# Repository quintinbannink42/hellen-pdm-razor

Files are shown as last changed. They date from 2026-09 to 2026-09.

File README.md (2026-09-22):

# PowerCore

Hellen-One **hardware** for **PowerCore**, a standalone automotive power distribution module (PDM) with a **Link Razor PDM**-compatible SuperSeal loom.

| | |
|---|---|
| **Product** | **PowerCore** (not an engine ECU) |
| **Connector** | 26-pin AMP SuperSeal 1.0 (Link “Connector C”) — pinout in [CONNECTOR.md](CONNECTOR.md) |
| **Main power** | M6 + / − (VBAT / GND), not on the SuperSeal |
| **MCU module** | [mega-mcu144](https://github.com/andreika-git/hellen-one/tree/master/modules/mega-mcu144) **rev ≥ 0.7** (STM32F767) |
| **I/O target** | 4× high-power (25 A / 80 A peak class) + 8× ADIO (8 A) |
| **KiCad stem** | `pdmrazora` (hellen-one: no dashes/underscores — **do not rename**) |
| **GitHub path** | `hellen-pdm-razor` (legacy repo name; product name is PowerCore) |
| **Default branch** | `main` (required by hellen-one automation) |

> **This is NOT [HELLCORE](https://github.com/quintinbannink42/HELLCORE).** HELLCORE is a separate project. PowerCore is a Hellen-One PDM carrier that matches the Link Razor loom connector.

Former working names (docs/history only): `hellen-pdm-razor`, Hellen Razor-class PDM.

## Docs

| File | Contents |
|---|---|
| [POWERCORE_BRIEF.md](POWERCORE_BRIEF.md) | Product identity, tokens, Razor loom compatibility |
| [CONNECTOR.md](CONNECTOR.md) | Exact Razor-compatible 26-pin + M6 pinout (authoritative) |
| [PINMAP.md](PINMAP.md) | mega-mcu144 edge → HP / ADIO / system nets |
| [REV1_SPEC.md](REV1_SPEC.md) | Goals, architecture, e-fuse behaviour |
| [BLOCK_DIAGRAM.md](BLOCK_DIAGRAM.md) | Carrier block diagram |
| [BOARD.md](BOARD.md) | What’s stubbed vs next; module placement steps |
| [HARDWARE_BOM.md](HARDWARE_BOM.md) | Chosen PNs, kILIS, AmpsPerVolt TODOs |

## KiCad project

Open with **KiCad 8.x** (Hellen mega-mcu144 0.7 is K8). KiCad 9 also works. KiCad 6/7 will not open this module.

- `pdmrazora.kicad_pro` / `.kicad_sch` / `.kicad_pcb` (no dashes/underscores — hellen-one requirement)
- `revision.txt` → `BOARD_PREFIX=pdm` `BOARD_SUFFIX=razor` `BOARD_REVISION=a`

Schematic: SuperSeal **TE 6473418-1** vertical (Link Razor-compatible nets; same pin numbers as former RA 9-6437287-8), **split** M6 bolt-through bobbins (J2 VBAT+ north / J3 GND south, drivers between) + power entry/IGN_SW divider, sheets **MM144** / **HP** (**BTS50010-1TAD** ×4) / **ADIO** (**BTS7004-1EPP** ×8 + sense/PU). PCB: **109×98 mm** frame (was 104×93), mega-mcu144 0.7 west of a vertical SuperSeal EMI wall, power/PROFET east. J2 VBAT+ and J3 GND stay on opposite edges of the power field; HP×4 and ADIO×8 are mirrored about x=80. `PWR_OUT1–4` run on exposed F.Cu (F.Mask opened over the copper) with short B.Cu hops only at the module pad wall. DRC shorts/crossings/clearance are 0; the board is not fab-clean (see [BOARD.md](BOARD.md)). Parts/kILIS: [HARDWARE_BOM.md](HARDWARE_BOM.md).

## How to build (Hellen-One)

1. `git clone --recurse-submodules https://github.com/quintinbannink42/hellen-pdm-razor.git`
2. Open with **KiCad 8.x** (Hellen mega-mcu144 0.7 is K8). KiCad 9 also works. KiCad 6/7 will not open this module.
   Open `pdmrazora.kicad_pro`.
3. mega-mcu144 **0.7** is already on the frame (`M1000`). Refresh from `hellen-one/modules/mega-mcu144/0.7/` if the submodule moves.
4. Route SuperSeal / M6 / module pads per CONNECTOR.md / PINMAP.md; replace HP/ADIO schematic stubs with chosen PNs + sense parts.
5. Push to **`main`**. GitHub Action `.github/workflows/create-board.yaml` calls hellen-one create-board to merge module gerbers into `boards/`.
6. Daily workflows keep `hellen-one` and `kicad6-libraries` submodule refs updated.

Frame rules (from hellen-example FAQ):

- No `-` or `_` in KiCad filenames
- `aux_axis_origin` required; board origin at **bottom-left** (no negative coordinates)

## Firmware intent

Firmware is **not** this repo. See **[fw-powercore](https://github.com/quintinbannink42/fw-powercore)** (rusEFI custom board overlay: electronic fuse + channel map), based on [fw-custom-hellen144-f4](https://github.com/rusefi/fw-custom-hellen144-f4) / `hellen-common-mega144.mk`, with `protected_gpio` for HP1–4 + ADIO1–4 first. See PINMAP.md and REV1_SPEC.md.

## Submodules

```
hellen-one          https://github.com/andreika-git/hellen-one
kicad6-libraries    https://github.com/rusefi/kicad6-libraries
```

Skeleton mirrors [rusefi/hellen-example](https://github.com/rusefi/hellen-example).

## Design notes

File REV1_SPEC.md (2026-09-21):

# PowerCore — Rev 1

**Status:** Rev 1 design baseline  
**Product:** PowerCore (standalone PDM; Link Razor-compatible SuperSeal loom)  
**MCU module:** Hellen mega-mcu144 (STM32F767)  
**Firmware base:** [fw-powercore](https://github.com/quintinbannink42/fw-powercore) (rusEFI custom board)  
**I/O target:** Link ECU Razor PDM I/O + protection parity  

Former working names (docs/history only): `hellen-pdm-razor`, Hellen Razor-class PDM. KiCad stem stays **`pdmrazora`**.

## Goals (rev 1)

Ship a first PowerCore Hellen-One carrier + firmware that can:

1. Drive **4× high-power** channels at **25 A continuous / 80 A peak**, HS (DIR/H-bridge optional if pins allow).
2. Provide **8× ADIO** at **8 A** high-side, with analog/digital input modes and software pull-ups.
3. Log **per-channel current** on high-power outputs (and ADIO when used as outputs).
4. Implement programmable electronic-fuse behaviour (inrush window, overcurrent, trip time, retry/latch, over-temp).
5. Speak **USB** + **CAN**; expose channels in TunerStudio / gauges.

Non-goals for rev 1: sealed Link-style CNC housing, PC “PDM Link” clone UI, full galvanic isolation, second MCU.

## Architecture

```
                    +------------------+
   VBAT ------------| Power entry      |
                    | TVS, reverse,     |
                    | fuse, sense      |
                    +--------+---------+
                             |
              +--------------+--------------+
              |                             |
     +--------v--------+           +--------v--------+
     | HP stage x4     |           | ADIO stage x8   |
     | PROFET / half-  |           | 8 A high-side   |
     | bridge capable  |           | + pin mux       |
     | IS -> ADC       |           | V/I -> ADC      |
     +--------+--------+           +--------+--------+
              | EN/PWM/DIR                  | EN/PWM/PU
              |                             |
              +--------------+--------------+
                             |
                    +--------v---------+
                    | mega-mcu144      |
                    | STM32F767        |
                    | USB / CAN / ADC  |
                    +--------+---------+
                             |
                    +--------v---------+
                    | SuperSeal I/O    |
                    | + USB-C          |
                    +------------------+
```

## Electrical targets (from Link Razor)

| Block | Count | Continuous | Peak / trip notes | Modes |
|---|---:|---|---|---|
| High-power | 4 | 25 A | 80 A safe peak; measure to ~60 A | HS (rev1); LS / half / full bridge stretch |
| ADIO | 8 | 8 A HS out | Fixed ~10 A hardware trip class | Analog in, digital in, HS out; ADIO1–4 PWM out; ADIO5–8 freq/PWM in |
| Supply | — | 6–24 V | 12/16 V nominal | Quiescent &lt;300 mA outputs off |
| Aux | — | 5 V sensor @ 50 mA/pin class | — | Sensor GND separate from chassis |

## Firmware electronic fuse (clone Razor behaviour)

Per high-power channel:

- **Inrush** limit + trip time + duration window after turn-on
- **Overcurrent** limit + trip time after inrush window
- **Fast short** path (~60 A class) → immediate off
- **Retry** (count + delay) or **latch-off**
- **Over-temp** board threshold with hysteresis
- Optional soft-start duty ramp on PWM channels

ADIO outputs: simpler fuse (fixed hardware trip + software trip time / retry / latch).

## Pin budget (mega-mcu144)

Provisional function map — STM32 / MM144 edge names filled from module docs in `PINMAP.md`.

| Function | Count | Notes |
|---|---:|---|
| HP_EN / PWM | 4 | TIM PWM ≥10 kHz |
| HP_DIR | 0–4 | Stretch; omit on first spin if copper tight |
| HP_ISENSE ADC | 4 | Continuous current |
| ADIO_EN / PWM | 8 | 4 with PWM timers |
| ADIO_PU | 8 | Soft 4k7 to 5 V |
| ADIO_SENSE ADC | 8–16 | Prefer V+I; 144 should allow at least V **or** I per pin without mux |
| Freq / PWM in | 4 | ADIO5–8 input path |
| VBATT / 5V / TEMP ADC | 3 | |
| USB | 1 | On module |
| CAN | 1 | On module |
| Status LEDs | ≥4 | Module LEDs + carrier if needed |
| PWR_EN | 1 | Switched 5 V sensor rail |

## Rev 1 hardware BOM direction

- **MCU:** Hellen mega-mcu144 module footprint
- **HP switches:** Infineon PROFET+2 / PROFET (e.g. BTS70xx class sized for 25 A continuous + inrush); IS pin to ADC via Rl
- **ADIO switches:** smaller PROFET / high-side (8 A continuous)
- **Connector:** 26-pin SuperSeal family (Razor-like dual pins on HP feeds)
- **USB-C** for config (RusEFI USB)
- **CAN** transceiver on module or carrier as per MM144 edge

## Firmware repo layout (planned)

```
fw-powercore/
  meta-info.env
  board.mk
  board_configuration.cpp   # pin map + defaults
  prepend.txt
  firmware/                 # electronic fuse + channel state machine
  README.md
```

Build via RusEFI custom-board GitHub Action pattern (`rusefi/fw-custom-example`).

## Build order

1. Freeze pin map (`PINMAP.md`) against MM144 edge  
2. Hellen-One KiCad frame + HP/ADIO modules  
3. Bring-up firmware: toggle HP/ADIO, read ADCs in TunerStudio  
4. Electronic-fuse state machine  
5. CAN channel command / status frames  

## Open items for next docs

- Exact MM144 edge → STM32 assignment (`PINMAP.md`)
- Chosen PROFET PNs and sense-resistor cal
- Connector pinout drawing
- CAN DBC draft

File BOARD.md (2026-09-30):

# Board status — PowerCore (`pdmrazora` rev a)

Open with **KiCad 8.x** (Hellen mega-mcu144 0.7 is K8). KiCad 9 also works. KiCad 6/7 will not open this module. File format stays **20240108 / generator_version 8.0**. Stem is `pdmrazora`.

## This commit — leftover rats and ADIO5/ADIO8 fill

Closes rats left after the U14/U16/U18 reconnect, and brings the two 2 oz fill residuals back to the 8 A floor. Applicators: `scripts/close_remaining_rats.py` (ADIO5/ADIO8 polish and the five EN ties) and `scripts/route_short_rats.py` (short pairs). Both are already applied; re-running them duplicates copper. `scripts/cut_crossings_sexp.py` was not replayed. `scripts/even_2oz_pour.py` was not re-run. No footprint moved. ADIO2 was not edited. HP pours were not trimmed. F1 stays open. There is still no SENSOR_GND pour. The Razor loom / SuperSeal map is unchanged. No gerbers. Pins were not frozen.

ADIO5 polish is a B.Cu sliver `A5_slot_ext` under the F slot only, outline (111.00, 45.46)–(113.45, 45.78), overlapping the ribbon bottom at y=45.58. The top of that slot stays against ADIO4. The ribbon was not lowered west of the slot, where ADIO6 sits 0.23 mm under it. ADIO8 polish moves the west edge of `A8_drop_F` from x=47.12 to x=47.08, into the gap beside PWR_OUT4 (fill ends at x=46.68). The east edge stays on ADIO6. Neither edit takes copper from ADIO2 or from a PWR_OUT pour.

Filled necks, 0.01 mm raster of the zone fill, same cuts on main and on this board except the two pinches:

| Path | Filled series neck | 2 oz floor |
|---|---|---|
| ADIO1 | 1.76 + 1.76 mm = 3.52 mm F+B, unchanged | 1.74 mm |
| ADIO2 | corridor not edited (4.53 mm) | 4.53 mm |
| ADIO3 | 1.03 + 1.03 mm = 2.06 mm F+B, unchanged | 1.74 mm |
| ADIO4 | alley 1.74 mm, drop 1.74 mm, throat 0.94 + 1.00 mm | 1.74 mm |
| ADIO5 | slot B **1.71 → 1.83 mm** (x=111.05–113.35) | 1.74 mm |
| ADIO6 | alley 1.74 mm, throat 0.88 + 0.88 mm = 1.76 mm | 1.74 mm |
| ADIO7 | east B ribbon 3.80 mm, unchanged | 1.74 mm |
| ADIO8 | drop **1.73 → 1.77 mm**; alley 1.73 mm unchanged (main is also 1.73); throat 0.90 + 0.90 mm | 1.74 mm |
| PWR_OUT1 | 19.21 mm F | 8.36 mm |
| PWR_OUT2 | 16.72 mm F | 8.36 mm |
| PWR_OUT3 | 21.40 mm F | 8.36 mm |
| PWR_OUT4 | 8.70 + 8.70 mm = 17.40 mm F+B | 8.36 mm |

The ADIO8 alley was already 1.73 mm filled on main. #26 wrote 1.74 mm for that alley. This pass did not narrow it and did not jog it: the named residual was the drop. Widening the alley would crowd the next even pour.

| Issue | Before (main `fc83f20`) | After |
|---|---:|---:|
| shorting_items / crossings / clearance / courtyard / padstack | 0 | **0** |
| unconnected_items | 158 | **141** |
| SuperSeal nets edited | — | **no** |

`kicad-cli` 8.0.9, `pcb drc --severity-error`. Violations 0. Unconnected 141.

What closed: EN pad 2–3 on U11 (`OUT_PWM5`), U13 (`OUT_PWM7`), U15 (`OUT_IO5`), U17 (`OUT_IO7`), and U12 (`OUT_PWM6`), 0.20 mm on F.Cu. Short same-net stitches on GND, SENSOR_5V (including SuperSeal pins 11 and 5, already the same net), SENSOR_GND (pins 12 and 6, already the same net), IN_AUX1 (C10.1–R10.2), and IN_VIGN (R2.1–R1.2). Ten M1000 GND fingers get a 0.20 mm exit out of the pour keepout (tracks are allowed there). Pre-fuse VBAT ties C1 to C2 and D1 toward the north zone with 0.40 mm tracks that stay north of the fuse body. The B.Cu GND zone self-rat at (−31.2, −39.2) closed on the refill.

Still open, and why:

- **U12 GND.** Pad 1 at (81.95, 144.05) to the U18 via at (103.55, 147.95). ADIO2 seals the west and south of that pad. The east gutter to the VBAT column is about 0.40 mm, and a via does not fit between B.Cu ADIO2 (ends x=82.70) and F.Cu VBAT (starts x=83.0). Moving U12 would pull the OUT pads off the 4.53 mm corridor. Footprint stays.
- **F1.** Zone (68.5, 1) to zone (54.5, 27.5) stays open. The schematic uses one VBAT net through the fuse.
- **VBAT post-fuse islands.** Three self-rats on the F zone at (54.5, 27.5). The split is the #26 ADIO4/ADIO8 sense slot near x=86.7–87.9. Bridging it cuts those taps. There is no B.Cu VBAT under the slot. M1000 N27 at (−11.5, 26.2) is still open to the post-fuse zone.
- **VBAT north stub.** Track at (102.65, −26.25) to the D1 track at (112, 10.15). C1, C2, and D1 are tied on the pre-fuse side; that stub still does not meet D1.
- **IN_AUX4**, four rats. The U4 stub (101.65, 40.47) to (97.6, 32) is blocked by the U4 VBAT pad and PWR_OUT4. M1000 S10 (2.70, 65.70) is still open to C40.1 and R40.2.
- **Sense pad 2.** R201 (ADIO1), R202 (ADIO2), R203 (ADIO3), R205 (ADIO5), R207 (ADIO7). Schematic intent is pad 2 on ADIOn and pad 1 on SENSOR_5V, same as the even taps #26 already closed. These five sit in the VBAT / SENSOR_5V row at y=56.20. A 0.12 mm path to the pour is blocked (nearest fill is 4.6 mm to 20 mm away). Left open.
- **F.Cu GND slivers** at (68, 76.2), and U15 / U17 pad 1. The slivers sit against ADIO2. A via there hits the ADIO2 ribbon. Not cut. One M1000 GND finger at (14.2, 59.35) has no clear exit. The other fingers are 0.20 mm SMD with a separate F and B pad, so a one-layer exit leaves the other finger ratted. They are too narrow for a via.
- **Longer signal rats** (IN_RES, IN_MAP, IN_O2S, and the rest of the 141). The short router stops at 8 mm. The paths run through foreign pours. Those pours were not sliced.

## Previous commit — reconnect U14/U16/U18 and even sense

Moved drivers U14, U16, and U18 are tied again: VBAT pad 15, GND pad 1, EN pads 2–3, and the IS pad. Sense pads R204.2, R206.2, and R208.2 land on ADIO4/6/8 with a 0.12 mm tap, the same class of connection as the odd-channel sense pads (those odd pads stay open). Applicator: `scripts/reconnect_moved.py`. `scripts/cut_crossings_sexp.py` was not replayed. `scripts/even_2oz_pour.py` was not re-run.

VBAT branches are priority 2 on B.Cu, the same 3.6 mm class as the existing driver column, not a new 25 A neck. Signals use exclusive south-east lanes (0.20 mm, 0.15 mm in the east margin) and 0.50 mm vias. The only preserved-pour edit is the east tip of `A1/A3/A5/A7_spur_Fw`, pulled from x=104.25 to x=102.20 so a sense slot fits beside PWR_OUT2. Spur height stays 3.80 mm. ADIO2 was not edited. HP pours were not trimmed. F1 stays open. There is still no SENSOR_GND pour. The Razor loom / SuperSeal map is unchanged. No gerbers. Pins were not frozen.

Filled necks on the same cuts, before and after this refill, did not move:

| Path | Filled series neck | 2 oz floor |
|---|---|---|
| ADIO1 | 1.76 + 1.76 mm = 3.52 mm F+B (documented 3.56) | 1.74 mm |
| ADIO2 | corridor not edited (4.53 mm) | 4.53 mm |
| ADIO3 | 1.03 + 1.03 mm = 2.06 mm F+B (documented 2.08) | 1.74 mm |
| ADIO4 | alley 1.75 mm, drop 1.74 mm, throat 0.94 + 1.00 mm | 1.74 mm |
| ADIO5 | 1.71 mm B through the F slot (same as the 2 oz fill) | 1.74 mm |
| ADIO6 | alley 1.74 mm, throat 0.88 + 0.88 mm = 1.76 mm | 1.74 mm |
| ADIO7 | east B ribbon 3.80 mm (documented 3.82) | 1.74 mm |
| ADIO8 | alley 1.74 mm, drop 1.73 mm, throat 0.90 + 0.90 mm | 1.74 mm |
| PWR_OUT1 | 16.72 mm, outline not edited | 8.36 mm |
| PWR_OUT2–4 | outlines not edited; class pours stay 16.72 mm | 8.36 mm |

ADIO5's filled reading is 1.71 mm on both the 2 oz board and this refill. The outline at that slot is still the 1.77 mm ribbon from the 2 oz merge. Nothing in this pass cut it.

| Issue | Before | After |
|---|---:|---:|
| shorting_items / crossings / clearance / courtyard / padstack | 0 | **0** |
| unconnected_items | 174 | **158** |
| SuperSeal nets edited | — | **no** |

The drop is the moved-driver pads and the three even sense pads. U12's GND rat to the new U18 via is still open. Old VBAT zone rats are still there, and the refill added one VBAT zone rat, one GND zone rat, and one IN_AUX4 rat. `kicad-cli` 8.0.9, `--severity-error`. Violations 0. Unconnected 158.

## Previous commit — board-wide 2 oz, ADIO4/6/8 at 8 A

Copper weight is **2 oz (70 µm) on both layers, for the whole board**. Fab notes are in the title block and on Dwgs.User. Stackup in `pdmrazora.kicad_pcb`: F.Cu 0.07 mm, FR4 core 1.46 mm, B.Cu 0.07 mm, finished 1.6 mm. Numbers: [scripts/adio_2oz.txt](scripts/adio_2oz.txt). Applicator: `scripts/even_2oz_pour.py` (run only from a clean board).

Board-wide 2 oz is the normal fab path. A board house sets copper weight per layer for the whole panel, not for a region of ADIO4/6/8. Selective heavy copper is a different process. The HP pours were already wider than the new 25 A line, so the whole board going to 2 oz does not require trimming them.

IPC-2221A external, k = 0.048, ΔT = 20 °C. Width scales as 1/thickness. The 1 oz ruler was 8 A → 3.47 mm and 25 A → 16.72 mm. At 2 oz that is **8 A → 1.74 mm** (1.736 mm) and **25 A → 8.36 mm** (8.359 mm). Netclass defaults in `pdmrazora.kicad_pro` follow that (ADIO_OUT 1.74, HP_OUT and VBAT 8.36). Existing HP and VBAT copper was not narrowed to the new default.

2 oz does not open the stock SuperSeal cage. With 2.0 mm pads the even door is still F+B 1.20 mm, under 1.74 mm. Pins 16, 17, 18 and 22, 23, 24, 25 are 1.60 mm pads (0.15 mm annular ring on the 1.3 mm drill). Pins 15 and 21 and the HP pads stay 2.0 mm. Pin 25 stays N/C. The Razor loom map is unchanged.

U14, U16, and U18 still had to move. At 1.74 mm, U14's old OUT sat inside the ADIO2 corridor, and U16/U18 still had no path into the y≈60 bay without cutting the odd pours, the HP pours, or ADIO2. They sit in the empty south-east: U18 (108, 150), U16 (120, 146), U14 (120, 156), all rotation 0. U12 stays at (84.80, 146).

The odd east ribbons were narrowed where a 1.74 mm even throat cannot exist beside a 3.80 mm odd ribbon on a 3.0 mm pitch. Downstream odd spurs and columns were not cut. ADIO2 was not edited.

| Path | Series neck (filled) | 2 oz / 20 °C target |
|---|---|---|
| ADIO1 | 1.78 + 1.78 mm = 3.56 mm F+B (pour not edited; prior notch reading 3.51 mm) | 1.74 mm |
| ADIO2 | 4.53 mm F+B corridor, not edited | 1.74 mm |
| ADIO3 | 1.04 + 1.04 mm = 2.08 mm F+B (was 3.80 mm B) | 1.74 mm |
| ADIO4 | 1.76 mm (throat F+B 1.98 mm, gate under A7 is F+B 3.18 mm) | 1.74 mm |
| ADIO5 | 1.74 mm B through the F slot at x=111.2–114.0 (was 3.80 mm B) | 1.74 mm |
| ADIO6 | 1.76 mm (throat F+B 1.80 mm) | 1.74 mm |
| ADIO7 | 3.20 mm F+B at the pin (1.60 + 1.60); east B ribbon still 3.82 mm | 1.74 mm |
| ADIO8 | 1.76 mm (throat F+B 1.84 mm) | 1.74 mm |
| PWR_OUT1–4 | unchanged 16.72 mm class (west leg (8.70−0.30)×2 = 16.80 mm) | 8.36 mm |

Series neck is the minimum F+B cross-section of one continuous path. F and B add on the same XY. Via drills are stitches, not summed as parallel slots. SuperSeal pads and the PROFET OUT clusters are the pad interface, not the neck.

Outline stays **(−32, −40)–(142, 162)**. F1 stays open (new copper starts at y=34.24; F1 pads are at y=15 and y=24.2). There is still no SENSOR_GND pour. No gerbers. `scripts/cut_crossings_sexp.py` was not replayed. Pins were not frozen. 80 A peak and the 150 A fuse class are still not traces.

| Issue | Before | After |
|---|---:|---:|
| shorting_items / crossings / clearance / courtyard / padstack / mask bridge | 0 | **0** |
| unconnected_items | 183 | **174** |
| Copper weight | 1 oz (not recorded) | **2 oz both layers** |
| SuperSeal nets edited | — | **no** |

Unconnected is lower because the new pours tie the even power paths. It is not zero. The moved drivers' VBAT pad 15, GND pad 1, and signal pads are open, and the sense pads R204.2 / R206.2 / R208.2 are open in the same way as the odd channels. The old VBAT zone rats are still there. `kicad-cli` 8.0.9, `--severity-error`. Violations 0. Unconnected 174.

## Previous commit — ADIO4/6/8 loom reassignment held

Pin reassignment was allowed, including a break from the Link Razor harness map, so ADIO4, ADIO6, and ADIO8 could reach a continuous ≥3.47 mm series neck at 1 oz. No assignment does. The board copper is unchanged. The SuperSeal net list is unchanged. Stackup stays 1 oz. The 8 A line was not derated. Audit: `scripts/even_reassign_audit.py`. Numbers: [scripts/even_reassign_audit.txt](scripts/even_reassign_audit.txt) and [scripts/adio_ampacity.txt](scripts/adio_ampacity.txt).

The upper bound ties every SuperSeal pin that is not already a preserved high-current net onto the candidate at once: pins **3, 4, 5, 6, 10, 11, 12, 16, 17, 18, 25**. Pins 2, 9, and 15 stay ADIO2. Pins 21–24 stay ADIO1/3/5/7. The PWR_OUT pins stay. Signal tracks and GND tracks are ignored (a pour may push them). Pads stay. Preserved zones stay: PWR_OUT1–4, ADIO1/2/3/5/7, VBAT priority ≥2, and VBAT that reaches the fuse band. Priority-1 GND pours are not obstacles. Grid 0.30 mm, clearance 0.20 mm. F and B add on the same XY.

| Path | Series neck under that upper bound | 20 °C need |
|---|---|---|
| ADIO1 | unchanged 3.51 mm | 3.47 mm |
| ADIO3 | unchanged 3.80 mm B | 3.47 mm |
| ADIO5 | unchanged 3.80 mm B | 3.47 mm |
| ADIO7 | unchanged 3.80 mm B | 3.47 mm |
| ADIO2 | unchanged poured 4.53 mm (audit grid reads 4.29 mm to U12) | 3.47 mm |
| ADIO4 | **2.60 mm** to the open field beside U14, then ADIO2 copper at the OUT pads | 3.47 mm |
| ADIO6 | **no positive-width path** to U16 | 3.47 mm |
| ADIO8 | **no positive-width path** to U18 | 3.47 mm |
| PWR_OUT1–4 | unchanged 16.72 mm class | 16.72 mm |

ADIO4's 2.60 mm pinch is (104.6, 114.7): F width is 0 on the edge of PWR_OUT2 `PO2_east`, and B is 2.60 mm in the gap just south of the ADIO7 B spur (y=109.55–113.35). Both are preserved, so that neck was not trimmed. Blanking the ADIO2 tube beside U14 (x=87.2–93.5, y=150.5–161) drops the ADIO2 reading from 4.29 mm to 0.40 mm, pinch (86.9, 144.7), so that tube is the series path to U12, not spare copper around U14.

ADIO6 and ADIO8 sit in the bay at y≈60 (U16 OUT x=72.85, U18 OUT x=95.75). The east alley past x=134 is reached from pin 25 at about 14 mm F+B and still does not enter that bay. The walls are the odd-channel pours (ADIO5 ribbon y=45.15–47.35 across to x=129.8, ADIO7 B ribbon y=40.25–44.05 to x=134, the four spur rows near y=82.5 / 91.5 / 100.5 / 109.5, and the columns at x=122–134) plus PWR_OUT1 `PO1_drop`, PWR_OUT2 `PO2_east` / `PO2_band` / `PO2_col`, and the ADIO2 B ribbon. The earlier ~0.80 mm figure does not survive on this board: `scripts/even_nc_pour.py`'s own corridor, with those pours as obstacles, does not reach U16 or U18. R208 at (94.83, 56.20) is still the crowd beside U18, on the far side of that wall.

Loom delta versus Link Razor: **none**. No pin changed old net to new net.

| Pin | Razor net on main | After this pass |
|----:|---|---|
| 2, 9 | N/C on the loom, ADIO2 on the PCB | same |
| 16 | ADIO4 | same |
| 17 | ADIO6 | same |
| 18 | ADIO8 | same |
| 25 | N/C | same |
| 3, 4, 5, 6, 10, 11, 12 | CANH, IGN_SW, SENSOR_5V, SENSOR_GND, CANL, SENSOR_5V, SENSOR_GND | same |

Outline stays **(−32, −40)–(142, 162)**. F1 stays open. There is still no SENSOR_GND pour. No gerbers. `scripts/cut_crossings_sexp.py` was not replayed. Pins were not frozen.

| Issue | Before | After |
|---|---:|---:|
| shorting_items / crossings / clearance / courtyard / padstack / mask bridge | 0 | **0** |
| unconnected_items | 183 | **183** |
| Board copper edited | — | **no** |
| SuperSeal nets edited | — | **no** |

`kicad-cli` 8.0.9, `--severity-error`. Violations 0. Unconnected 183.

## Previous commit — even ADIO NC bridges

ADIO2 now has a poured series neck of **4.53 mm** F+B, above the 1 oz / 20 °C line for 8 A (3.47 mm). SuperSeal pins 2 and 9 join the ADIO2 net on the PCB so the west cage slots merge into that one corridor. The loom table still calls those pins N/C: no harness wire is added, and no signal pin was reassigned. Applicator: `scripts/even_nc_pour.py`. Numbers: [scripts/adio_ampacity.txt](scripts/adio_ampacity.txt).

Pin 25 stays N/C. Joining it to ADIO8 does not produce a continuous path to U18 at 3.47 mm (widest zone-aware path is about 0.80 mm, pinch beside U18). ADIO4 and ADIO6 stay at that same ~0.80 mm path once the odd pours and the PWR_OUT copper are treated as obstacles. The pad-only sum of every 0.52–0.60 mm slot around one pin (~5.66 mm) is not a series neck and was not poured. ADIO7's B.Cu leg was not moved.

Outline stays **(−32, −40)–(142, 162)**. F1 stays open. There is still no SENSOR_GND pour. Copper is still 1 oz. No gerbers.

| Path | Series neck | 20 °C need |
|---|---|---|
| ADIO1 | 1.75 + 1.76 mm = 3.51 mm, no via | 3.47 mm |
| ADIO3 | 3.80 mm B.Cu under PWR_OUT2 east | 3.47 mm |
| ADIO5 | 3.80 mm B.Cu under PWR_OUT2 east | 3.47 mm |
| ADIO7 | 3.80 mm B.Cu (outline not moved) | 3.47 mm |
| ADIO2 | 4.53 mm F+B filled corridor via pins 2 and 9 | 3.47 mm |
| ADIO4 | not poured; widest path ~0.80 mm | 3.47 mm |
| ADIO6 | not poured; widest path ~0.80 mm | 3.47 mm |
| ADIO8 | not poured; widest path ~0.80 mm with pin 25 | 3.47 mm |
| PWR_OUT1–4 | unchanged 16.72 mm class pours | 16.72 mm |

Series neck is the minimum F+B cross-section of one continuous path (filled copper, layers on the same XY add, via drills are holes the path goes around). It is not the sum of parallel slots.

| Issue | Before | After |
|---|---:|---:|
| shorting_items / crossings / clearance / courtyard / padstack / mask bridge | 0 | **0** |
| unconnected_items | 184 | **183** |
| SENSOR_GND pours | 0 | **0** |
| F1 bridged | no | **no** |
| In1.Cu count | 181 | **181** |

Unconnected is one lower. ADIO2's power path dropped from 7 open items to the one sense pad (R202.2 at y=56.20), same class as the odd channels. GND went 55 → 60 because the B.Cu ribbon pushes priority-1 GND aside. `kicad-cli` 8.0.9, `--severity-error`. `scripts/cut_crossings_sexp.py` was not replayed. Pins were not frozen.

## Previous commit — even ADIO fanout

ADIO2, ADIO4, ADIO6, and ADIO8 still do not have a 3.47 mm neck. A read-only corridor search (`scripts/even_adio_fanout.py`, also `scripts/adio_ampacity.py --even-audit`) may leave each even pin in any direction, on F.Cu and on B.Cu. The widest single neck is **0.60 mm on a layer, F+B 1.20 mm**. The 1 oz ceiling, with copper flush to the 1.3 mm drills and zero clearance (a short to the next plating), is **F+B 3.40 mm**, still under 3.47 mm. Detail: [scripts/adio_ampacity.txt](scripts/adio_ampacity.txt).

Odd ADIO necks and the PWR_OUT pours were not rewritten. The board file was not edited. Outline stays **(−32, −40)–(142, 162)**. F1 stays open. There is still no SENSOR_GND pour.

| Path | Series neck | 20 °C need |
|---|---|---|
| ADIO1 | 1.754 + 1.760 mm = 3.51 mm, no via | 3.47 mm |
| ADIO3 | 3.80 mm B.Cu under PWR_OUT2 east | 3.47 mm |
| ADIO5 | 3.80 mm B.Cu under PWR_OUT2 east | 3.47 mm |
| ADIO7 | 3.80 mm B.Cu (F ends at the PWR_OUT3 column) | 3.47 mm |
| ADIO2, 4, 6, 8 | 0.60 + 0.60 mm = 1.20 mm after the fanout search | 3.47 mm |
| PWR_OUT1–4 | unchanged 16.72 mm class pours | 16.72 mm |

Vias do not help: the SuperSeal pads are PTH on both layers. Moving the even drivers, opening a south or east corridor, or growing the board does not widen the door, which is upstream of that copper. Giving NC pins 2 and 9 to one even net, and pin 25 to another, can open ADIO2 or ADIO4 (not both) and ADIO8. ADIO6 stays at 1.20 mm even if it takes every NC pin. That reassignment was not applied; the Razor pin map is unchanged. Parallel 0.60 mm slots were not poured.

| Issue | Before | After |
|---|---:|---:|
| shorting_items / crossings / clearance / courtyard / padstack / mask bridge | 0 | **0** |
| unconnected_items | 184 | **184** |
| Board copper edited | — | **no** |

`kicad-cli` 8.0.9 numbers are the odd-pour pass. This pass did not change `pdmrazora.kicad_pcb`. No gerbers. `scripts/cut_crossings_sexp.py` was not replayed.

## Previous commit — ADIO 8 A pours

ADIO1, ADIO3, ADIO5, and ADIO7 now have a continuous J1-to-driver pour at the IPC-2221A 1 oz / 20 °C line for 8 A. ADIO2, ADIO4, ADIO6, and ADIO8 stay open: each SuperSeal exit is a 0.60 mm aperture (F+B = 1.20 mm). Coordinates, the width table, and the footprint moves: [scripts/adio_ampacity.txt](scripts/adio_ampacity.txt). Applicator: `scripts/adio_ampacity.py` (run only from a clean `pdmrazora.kicad_pcb`).

Outline stays **(−32, −40)–(142, 162)**. HP zones were not rewritten. F1 stays open, the post-fuse feeder stays **(84.80, 23.40)–(101.70, 29.20)**, and there is still no SENSOR_GND pour. 80 A peak on the HP outs stays pour plus the existing F.Mask hatch.

| Path | Before | After, series neck | 20 °C need |
|---|---|---|---|
| ADIO1 | open | 1.754 + 1.760 mm = 3.51 mm, no via | 3.47 mm |
| ADIO3 | open | 3.80 mm B.Cu under PWR_OUT2 east | 3.47 mm |
| ADIO5 | open | 3.80 mm B.Cu under PWR_OUT2 east | 3.47 mm |
| ADIO7 | open | 3.80 mm B.Cu (F ends at the PWR_OUT3 column) | 3.47 mm |
| ADIO2, 4, 6, 8 | open | blocked, 0.60 mm slot, F+B 1.20 mm | 3.47 mm |
| PWR_OUT1–4 | 16.72 mm class | same pours, same filled cross-sections | 16.72 mm |

J3 moves to **(−14, 108)**. U11, U13, U15, and U17 form a column at x=84.8 (y=82, 91, 100, 109, rotation 0, OUT east). U12 and U14 park in the south reserve at y=146 and y=154. C20, C40, and R20 move off the new spurs. U16 and U18 stay. The south reserve is 25 mm tall, so it holds the two parked drivers; the 3.47 mm copper uses the east margin and a via-free B.Cu underpass of PWR_OUT2.

| Issue | Before | After |
|---|---:|---:|
| shorting_items / crossings / clearance / courtyard / padstack / mask bridge | 0 | **0** |
| unconnected_items | 183 | **184** |
| SENSOR_GND pours | 0 | **0** |
| F1 bridged | no | **no** |
| In1.Cu count | 181 | **181** |

Unconnected is one higher because 172 foreign tracks were removed where they crossed the new zones (no PWR_OUT copper) and the moved parts left their old GND and signal copper. The four odd power paths themselves dropped from 7 open items to 1: the remaining item on each is a sense pad on the y=56.20 resistor row (R201, R203, R205, R207), which is not the 8 A neck. `kicad-cli` 8.0.9, `--severity-error`.

## Previous commit — ampacity floorplan (174×202)

The 109×98 packing cannot hold a 16.72 mm HP neck or a 3.47 mm ADIO neck. This pass grows the outline and shifts M1000 and the west HP drivers so PWR_OUT1–4 have a continuous pour at the IPC-2221A 1 oz / 20 °C line. J1, J2, J3, and F1 stay put. Netclasses are unchanged (HP_OUT 16.72, ADIO_OUT 3.47, VBAT 16.72). Coordinates and the before/after table: [scripts/floorplan_ampacity.txt](scripts/floorplan_ampacity.txt). Applicator: `scripts/floorplan_ampacity.py` (run only from a clean `pdmrazora.kicad_pcb`).

Outline **(0, 0)–(109, 98)** becomes **(−32, −40)–(142, 162)**: **109×98 → 174×202 mm** (+65 mm wide, +104 mm tall). M1000 moves (−30, 0) to (−28, 66). Its board keepout and the footprint keepout both move with it and are inflated to **(−29.1, 24.8)–(15.4, 67.1)** so edge pads stay inside the pour ban. U1 +10 mm, U3 +12 mm. A handful of passives leave the new corridors (listed in the floorplan note). EMI split is unchanged: the module still ends west of the SuperSeal courtyard.

80 A peak is still not a trace (~83 mm). It stays pour plus F.Mask solder-blob openings on the HP pours (352 strokes, was 358). F1 is not bridged: the post-fuse feeder is now **(84.80, 23.40)–(101.70, 29.20)**, 16.90 mm, with the same Y gap. No SENSOR_GND pour. No gerbers. `scripts/cut_crossings_sexp.py` was not replayed.

Series necks below are filled-zone cross-sections. F and B legs on the same path add. A 0.30 mm via drill is subtracted once per layer it pierces. SuperSeal pads are 2.0 mm and the PROFET OUT clusters are ~3.3 mm tall; those pad interfaces are not the 16.72 mm neck.

| Path | Before (audit) | After, series neck | 20 °C need |
|---|---|---|---|
| PWR_OUT1 | 0.20 mm | 8.55 + 8.60 mm hole bypass, then 16.72 mm | 16.72 mm |
| PWR_OUT2 | 0.20 mm | 16.72 mm column, band, and east drop | 16.72 mm |
| PWR_OUT3 | 0.20 mm | 18.22 mm gallery − 0.30 drill, 19.80 mm B drop − 0.30, 19.80 mm F landing − 0.60, then 16.72 mm | 16.72 mm |
| PWR_OUT4 | 0.20 mm | (8.70 − 0.30) mm F+B = 16.80 mm west leg, then 17.80 − 0.30 mm top band and 16.72 mm east | 16.72 mm |
| ADIO6 | 0.15 mm, complete | removed | 3.47 mm |
| ADIO1–5, 7, 8 | not routed | still open | 3.47 mm |
| VBAT post-fuse | 17.5 mm zone | 16.90 mm zone, F1 gap open | 16.72 mm |

ADIO was not re-poured. The SuperSeal pin gaps are 1.0 mm, and J3 sits on the U16 OUT column, so a 3.47 mm ADIO pour cannot leave the connector. The south margin under the PWR_OUT2 band (y=136.72 to the edge at 162) is left clear for that routing later.

| Issue | Before | After |
|---|---:|---:|
| shorting_items / crossings / clearance / hole / courtyard / padstack / mask bridge | 0 | **0** |
| unconnected_items | 46 | **183** |
| Pour verts inside M1000 keepout | 0 | **0** |
| SENSOR_GND pours | 0 | **0** |
| F1 bridged | no | **no** |
| F.Mask drawings on PWR_OUT | 358 | **352** |
| In1.Cu count | 181 | **181** |

Unconnected rose because the old 0.15–0.20 mm HP and ADIO tracks were deleted, M1000 wall tracks that left the module were dropped, and the moved passives are no longer on their old copper. By net: GND 46, ADIO1–8 ×7 (56), SENSOR_5V 10, VBAT 6 (the fuse gap is still in there), plus the signal nets that used to ride the deleted copper. `kicad-cli` 8.0.9, `--severity-error`.

## Previous commit — track-width audit and post-fuse VBAT feeder

Copper weight is not in the board file (only `(thickness 1.6)`). Widths below use **IPC-2221A external, 1 oz / 35 µm**, pass line **≤20 °C** (top of the 10–20 °C band). 25 A needs **16.72 mm**; 8 A needs **3.47 mm**. The 8–12 mm guess matches 2 oz, which this file does not specify. Full table: [scripts/track_width_audit.txt](scripts/track_width_audit.txt).

HP and ADIO tracks that are already routed stay at 0.15–0.20 mm along the long runs. The corridor beside each of those runs is already at 0.20 mm clearance (J3 pad, the other channel, the board edge, M1000). Widening them to 16.7 mm or 3.5 mm needs a layout change, so those tracks were not moved. 80 A peak needs ~83 mm and is not a continuous width; the 358 F.Mask openings on `PWR_OUT` are still there. Fifteen openings that were 0.15 mm on 0.50–0.70 mm copper are now copper−0.08 mm.

The one neck that was a track inside a wide pour is the post-fuse VBAT entry. F1.2 used to leave on a **2.0 mm** F.Cu strap (~5 A). A priority-2 F.Cu zone `VBAT_post_fuse_feeder` at **(90.5, 23.4)–(108.0, 29.2)** fills **17.5 mm** (~26 A at 20 °C, about 19 °C at 25 A) and joins the existing pour, which is already ~53 mm wide at y=28. It does not touch the pre-fuse pour or F1.1. B.Cu there is the GND return and was left alone. The pre-fuse pour (about 16 mm F + 17 mm B at x=98.5, ~41 A) and the y=55 pour neck (7.5 mm F + 8.0 mm B at x≈99–106) still cannot carry the 150 A fuse.

Netclasses `HP_OUT` / `ADIO_OUT` / `VBAT` now default new routes to 16.72 / 3.47 / 16.72 mm. Existing vias stay 0.6 / 0.3 mm; a 0.30 mm drill is ~0.7 mm of 1 oz and is called out as a neck, not enlarged.

| Issue | Before | After |
|---|---:|---:|
| shorting_items / crossings / clearance / hole / courtyard / padstack | 0 | **0** |
| unconnected_items | 46 | **46** |
| Pour verts inside M1000 keepout | 0 | **0** |
| SENSOR_GND pours | 0 | **0** |
| F1 bridged | no | **no** |
| F.Mask drawings on PWR_OUT | 358 | **358** |
| Post-fuse VBAT entry width | 2.0 mm track | **17.5 mm** F.Cu zone |

`kicad-cli` 8.0.9, `--severity-error`. No gerbers. `scripts/cut_crossings_sexp.py` was not replayed. No footprint moves.

## Previous commit — ADIO rest attempt (no copper kept)

Does not move the outline, AUX origin, EMI split, bobbins, or any footprint. `scripts/cut_crossings_sexp.py` was not replayed. No SENSOR_GND pour. F1 is not bridged. No gerbers: unconnected stays **46**, still more than the fuse gap plus the M1000 keepout.

One serious attempt to replicate the ADIO6 pattern (local wall jog → B.Cu spine → via on driver F.Cu → B.Cu pour keepout → GND stitch) for ADIO1,2,3,4,5,7,8. Candidates that closed an ADIO ratsnest always opened at least one GND island (ADIO5 also grew VBAT 33→34), so nothing was kept. Stopped; see mm blockers below.

[F.Cu / B.Cu overview](scripts/copper_fill_overview.png). [Neck crop with open ADIO ends](scripts/adio_rest_blockers.png) — yellow ADIO, red keepout boxes, ADIO6 spine annotated. [ADIO6 reference](scripts/neck_adio6.png). Report: [scripts/drc_109.txt](scripts/drc_109.txt). Notes: [scripts/adio_rest_blockers.txt](scripts/adio_rest_blockers.txt). Harness: `scripts/land_adio_rest.py`.

| Issue | PR #17 / main `045cf4b` | After this pass |
|---|---:|---:|
| shorting_items | 0 | **0** |
| tracks_crossing | 0 | **0** |
| clearance | 0 | **0** |
| hole_near_hole | 0 | **0** |
| solder_mask_bridge | 0 | **0** |
| courtyards_overlap | 0 | **0** |
| padstack_invalid | 0 | **0** |
| unconnected_items | 46 | **46** |
| Pour verts inside M1000 keepout | 0 | **0** |
| SENSOR_GND pours | 0 | **0** |
| F1 bridged by pour | no | **no** |
| Footprints moved | 0 | **0** |
| Tracks / vias | 1297 / 207 | **1297 / 207** |
| F.Mask drawings on PWR_OUT | 358 | **358** |

| Net group | PR #17 | After this pass |
|---|---:|---:|
| GND | 23 | **23** |
| SENSOR_5V | 3 | **3** |
| VBAT | 10 | **10** |
| ADIO1–8 | 7 | **7** (ADIO6 only) |
| IGN_SW / IN_AUX4 / OUT_PWM8 | 3 | **3** |

### mm blockers (why ADIO6 did not generalize)

| Net | Geometry | Blocker |
|-----|---|---|
| ADIO2 | Bus to (70.8, 80.6) and B spine to y=62 clear. F landing ~**(71.8, 52.0)** | `SENSOR_5V` y=56.25 (~0.42 mm off col), `OUT_IO7` at x=71.2, `OUT_IO6`/`OUT_PWM2`/`IN_MAP3`/`IN_O2S`/`OUT_IO8`. F stub to y=62 hits ADIO6/ADIO5 F copper. |
| ADIO4 | Column x=23.7 at (23.7, 73) | `IN_RES3` via **(23.2, 76.0)**: center dist **0.50 mm**, need **0.525 mm** (short **0.025 mm**). Trial via nudge to 23.05 opens south bus to x≈72; ADIO6 keepout/J3 then block U14. |
| ADIO8 | Bus (72.0, 82.0); east at y=82 only to x=73 (J3) | No clear `(73→95.8)` row in y=70–84. Vertical x=95.8 blocked y=78–70 (`IN_RES3`/`OUT_PWM2`/`IN_RES1`). East-skirt BFS reaches U18 but cuts B-only GND ~**(98,54)–(103,62)** with no F pour to stitch → unconnected does not drop. |
| ADIO5 | BFS pin (42.3, 46.5)→via (64.2, 60.8) exists | Keepout+stitch closes ADIO5 but **VBAT islands 33→34**, unconnected 46→47. |
| ADIO1/3/7 | Odd J1 pins | No BFS to driver copper within 400k expansions. |
| Secondary | C101/C102/R101/U15/U16/U18 GND; IGN_SW; IN_AUX4; OUT_PWM8; SENSOR_5V R201/R205 | No pad∩B-pour via that drops count; long-haul nets not opened this pass. |

### Still open

Same 46 as PR #17. No gerbers.

## Previous commit — open the GND neck and land ADIO6

Does not move the outline, AUX origin, EMI split, bobbins, or any footprint. `scripts/cut_crossings_sexp.py` was not replayed. No SENSOR_GND pour. F1 is not bridged. No gerbers: the leftover is still more than the fuse gap plus the M1000 keepout.

[F.Cu / B.Cu overview](scripts/copper_fill_overview.png) — gold tracks are `PWR_OUT1–4`, yellow on B.Cu is ADIO. [Neck crop](scripts/neck_adio6.png) — yellow is the ADIO6 spine. [R10 stitch](scripts/r10_stitch.png) — the B.Cu tie from R10.1 to the C10 via. [C105 / C106 / C107](scripts/in_res2_c105.png) — the widened channel and the three vias. [Exposed HP copper](scripts/hp_mask_openings.png) — gold is F.Cu, red is the F.Mask opening. Mask drawings on those nets stayed at **358**. Openings were not covered.

`kicad-cli pcb drc` **8.0.9**, `--severity-error`, `--units mm`. Report: [scripts/drc_109.txt](scripts/drc_109.txt). Edits: `scripts/open_neck.py`, `scripts/widen_in_res2.py`, `scripts/stitch_pads.py`. Rebased onto main `b044550` (PR #16 squash).

| Issue | main `b044550` | After this pass |
|---|---:|---:|
| shorting_items | 0 | **0** |
| tracks_crossing | 0 | **0** |
| clearance | 0 | **0** |
| hole_near_hole | 0 | **0** |
| solder_mask_bridge | 0 | **0** |
| courtyards_overlap | 0 | **0** |
| padstack_invalid | 0 | **0** |
| unconnected_items | 51 | **46** |
| Pour verts inside M1000 keepout | 0 | **0** |
| SENSOR_GND pours | 0 | **0** |
| F1 bridged by pour | no | **no** |
| Footprints moved | 0 | **0** |
| Tracks / vias | 1273 / 201 | **1297 / 207** |
| F.Mask drawings on PWR_OUT | 358 | **358** |

Against the pre-#16 main (`6c243d8`, 64 unconnected): hard DRC rows stay 0, unconnected is 64 → 46, mask openings stay 358.

### What changed

The hop from the ADIO6 bus at (66.0, 81.4) onto U16 crosses the B.Cu GND neck and would seal the pour between the M1000 keepout (south edge y=65.9) and the y≈81 buses. The column that reaches the driver pad is x=72.4, and OUT_IO7 was using it.

OUT_IO7 B.Cu (79.2, 62.4)–(71.2, 62.4) and (71.2, 62.4)–(71.2, 59.6), both width 0.20, are replaced by (79.2, 62.4)→(73.6, 62.4)→(73.6, 61.4)→(71.2, 61.4)→(71.2, 59.6), still width 0.20. That leaves x=72.4 clear down to the existing F.Cu ADIO6 copper at y=62.0.

ADIO6 then runs B.Cu (66.0, 81.4)→(72.4, 81.4)→(72.4, 62.0), via 0.50/0.30 at (72.4, 62.0), and a 0.15 mm F.Cu tie to (72.8, 62.0). A B.Cu-only pour keepout covers (71, 63)–(75, 81) so the spine does not leave a pour sliver. Tracks, vias, and pads are still allowed there. A GND via 0.50/0.30 at (68.6, 79.0) sits in both the cut-off B pour and the F.Cu pour around J3, so the island ties back through the J3 PTH. The pair diff of the DRC report is one line: the ADIO6 ratsnest is gone. GND stays 26 and VBAT stays 10.

IN_RES2 was a 0.60 mm channel. OUT_PWM2 B.Cu (48.4, 54.8)–(92.0, 54.8) now jogs to y=55.15 between x=81.40 and x=90.8 (still 0.25 mm clear of OUT_IO8 at y=55.60). IN_O2S2 B.Cu (81.6, 54.0)–(92.8, 54.0) jogs to y=54.68 between x=82.15 and x=90.2. Via 0.50/0.30 at (89.22, 54.05) sits on C107.1, and a 0.15 mm B.Cu tie drops to the stub at y=53.20. The same slot then takes GND vias on C105.2 (82.775, 54.05) and C106.2 (86.775, 54.05), each with a 0.15 mm B.Cu tie down to the existing run at y=52.40.

R10.1 was walled into a 0.60 mm B.Cu slot, so the pour never reached the pad. C10.2 was already on that pour through the via at (63.175, 76.20). IN_O2S B.Cu moves to y=75.90 between x=56.8 and x=58.35, and IN_RES2 B.Cu moves to y=77.10 between x=56.45 and x=58.45. Via 0.50/0.30 at (57.375, 76.48) sits on R10.1, and a 0.15 mm B.Cu tie runs to the C10 via. VBAT island count stays 33. Taken together, the two jogs also move one B.Cu GND ratsnest anchor to the zone corner (0.8, 0.8). Each jog by itself does not.

| Net group | main `b044550` | After this pass |
|---|---:|---:|
| GND | 26 | **23** |
| SENSOR_5V | 3 | **3** |
| VBAT | 10 | **10** |
| ADIO1–8 | 8 | **7** (ADIO6 closed) |
| IGN_SW / IN_AUX4 / OUT_PWM8 | 3 | **3** |
| IN_RES2 | 1 | **0** |

### Still open

| Count | What it is |
|---:|---|
| 23 | GND. **11** are M1000 keepout F/B pairs, and one more is the keepout pair between the pads at (44.20, 65.00) and (44.20, 59.35). C10.2, R10.1, C105.2, and C106.2 are on the pour. Still open: C101.2, C102.2, R101.1, U15.1, U16.1, U18.1, track-to-track islands, and one B.Cu zone fragment anchored at (0.8, 0.8). A via on the open pads does not also land in the pour. |
| 10 | VBAT. One is the intentional fuse gap: pre-fuse zone anchor (68.5, 1.0) vs post-fuse (54.5, 27.5). One is M1000.N27 (18.50, 26.20). The other eight are post-fuse islands. Not bridged. |
| 7 | ADIO1, ADIO2, ADIO3, ADIO4, ADIO5, ADIO7, ADIO8. ADIO6 is on the driver. ADIO2 can reach (70.8, 80.6) on B.Cu and has a legal via on its F.Cu copper at (72.3, 52.0), but OUT_IO7's via at (71.2, 59.6), SENSOR_5V at y=56.2, OUT_PWM2 at y=54.8, IN_MAP3 at y=54.0, and IN_O2S at y=52.8 close every column before that via. ADIO8 cannot step east of x=72 at y=82 (J3 pad, then the ADIO6 spine). ADIO4 cannot leave (23.7, 73): IN_RES3 occupies x=23.2. The odd pins are still on J1. |
| 3 | SENSOR_5V edges. R201.1 and R205.1 (R205 is in two edges). R202 and R206 are already tied. No via lands on R201 or R205; ADIO1 / IN_MAP2 sit on the R201 pad and ADIO4 / ADIO5 sit on R205. |
| 1 | IGN_SW. J1.4 (34.30, 46.50) to R1.1 (55.175, 18.50). The pin's pocket is only y=44.0–48.3. B.Cu at x=1.2 is clear from y=40 to y=18, west of M1000, but the module's west pad row at x≈2.3 is on a 1.0 mm pitch with a 0.40 mm copper gap, so nothing enters that column. PWR_OUT4 at x=16.5 and the SENSOR_GND bypass at x=12 block the straight west run. PWR_OUT copper was not moved. |
| 1 | IN_AUX4. M1000.S10 (32.70, 65.70) to C40.1 (96.825, 32.20). |
| 1 | OUT_PWM8. M1000.E28 (44.00, 49.60) to the B.Cu track at (90.00, 47.80). The reachable pocket is only x=43.6–45.2, y=49.3–64.4. |

No gerbers. 46 unconnected is more than the fuse gap plus the M1000 keepout.

## Previous commit — corridors and pour stitches

Does not move the outline, AUX origin, EMI split, bobbins, or any footprint. `scripts/cut_crossings_sexp.py` was not replayed. No SENSOR_GND pour. F1 is not bridged. No gerbers: the leftover is still more than the fuse gap plus the M1000 keepout.

[F.Cu / B.Cu overview](scripts/copper_fill_overview.png) — gold tracks are `PWR_OUT1–4`, yellow on B.Cu is the ADIO west exit. [Exposed HP copper](scripts/hp_mask_openings.png) — gold is F.Cu, red is the F.Mask opening. Mask drawings on those nets stayed at **358**. Openings were not covered.

`kicad-cli pcb drc` **8.0.9**, `--severity-error`, `--units mm`. Report: [scripts/drc_109.txt](scripts/drc_109.txt). Router: `scripts/open_corridors.py`.

| Issue | PR #15 | After this pass |
|---|---:|---:|
| shorting_items | 0 | **0** |
| tracks_crossing | 0 | **0** |
| clearance | 0 | **0** |
| hole_near_hole | 0 | **0** |
| solder_mask_bridge | 0 | **0** |
| courtyards_overlap | 0 | **0** |
| padstack_invalid | 0 | **0** |
| unconnected_items | 64 | **51** |
| Pour verts inside M1000 keepout | 0 | **0** |
| SENSOR_GND pours | 0 | **0** |
| F1 bridged by pour | no | **no** |
| Footprints moved | 0 | **0** |
| Tracks / vias | 1232 / 190 | **1273 / 201** |
| F.Mask drawings on PWR_OUT | 358 | **358** |

### What changed

The SENSOR_GND B.Cu spine at x=38.40 (y=43.20–55.60, width 0.20) is gone, along with the three vias that tied it (38.00, 43.20), (39.20, 55.60), (43.20, 61.20). Replacement is a 0.15 mm B.Cu bypass from J1.12 at (36.60, 41.60) west to x=12.00, south to (12.00, 63.60), and a 0.50/0.30 via onto the existing F.Cu SENSOR_GND bus at y=63.60. The F.Cu J1.6↔J1.12 ties stay. SENSOR_GND is still tracks and vias only.

The F.Cu SENSOR_5V spine at x=38.40 (y=46.40–62.00) moved with it. Replacement is a B.Cu drop at x=10.00 from the existing F.Cu run at y=43.60 onto the F.Cu bus at y=62.40, with a via at each end.

That opens the 1.00 mm slot between the middle SuperSeal column (x=36.80) and the west ADIO column (x=39.80). ADIO2, ADIO4, ADIO6, and ADIO8 each leave their pin on B.Cu through their own column gap, then a private lane and a private S-row passage down to y=73. ADIO8 continues to (72.0, 82.0) and ADIO6 to (66.0, 81.4). Those buses stay at y≥80 so they do not cross the GND pour neck at y≈76–78. The last hop from that bus onto the driver copper does cross the neck (or the east board edge) and isolates a GND island, so it is not in this board. ADIO1/3/5/7 are still on their J1 pins. All eight ADIO ratsnest lines remain; the west pins now have a legal exit.

GND stitches, all clearance-checked, no footprint moves:

| Copper | What it ties |
|---|---|
| B.Cu (77.20, 52.40)→(78.90, 51.00) plus via (77.175, 52.40) | R104.1 onto the B pour |
| F.Cu (90.80, 54.30)→(92.60, 53.60)→(92.60, 52.40) | C107.2 |
| F.Cu (66.80, 54.30)→(69.20, 52.40) | C101.2 |
| F.Cu (74.80, 54.30)→(73.90, 55.10)→(72.40, 55.10)→(72.50, 53.60)→(72.90, 51.70) | C103.2 |
| F.Cu (69.90, 50.40)→(69.90, 52.20) | U11.1 |
| Via in pad, ring already in the B pour | R2.2 (56.00, 20.675), C104.2 (78.775, 54.225), C1.2 (63.50, 6.55), D1.2 (106.00, 19.85), R20.1 (100.975, 77.00), C20.2 (98.375, 77.00) |
| Via on the south edge of the pad | C10.2 (63.175, 76.20). Joins a pour island. The pad itself stays on the ratsnest. |
| F.Cu (94.15, 6.20)→(103.90, 6.20) plus via (103.90, 6.20) | C2.2, via ring already in the B pour |
| Via (94.775, 54.30) plus B.Cu (94.775, 54.30)→(98.20, 54.30)→(98.20, 52.10)→(97.90, 51.80)→(91.90, 51.80) | C108.2 onto the B pour |

A longer F.Cu stitch from R102 down to y≈46 closed two more GND pads and opened a VBAT island. It is not in this board. VBAT stays at 10.

SENSOR_5V: via at R202.1 (69.175, 56.20) and a B.Cu track to (73.60, 56.30). The other pull-up pads in that row do not accept a via.

| Net group | PR #15 | After this pass |
|---|---:|---:|
| GND | 38 | **26** |
| SENSOR_5V | 4 | **3** |
| VBAT | 10 | **10** |
| ADIO1–8 | 8 | **8** |
| IGN_SW / IN_AUX4 / IN_RES2 / OUT_PWM8 | 4 | **4** |

### Still open

| Count | What it is |
|---:|---|
| 26 | GND. **13** are M1000 keepout F/B pairs. The other **13** are 10 carrier pads the pour still misses (C10.2, C101.2, C102.2, C105.2, C106.2, R10.1, R101.1, U15.1, U16.1, U18.1) plus three track-to-track islands. No via inside those pads lands in the pour. R101 has an F.Cu path through y≈46 that reaches a pour via and drops GND by one, and it opens two VBAT islands, so it is not routed. |
| 10 | VBAT. One is the intentional fuse gap: pre-fuse zone anchor (68.5, 1.0) vs post-fuse (54.5, 27.5). One is M1000.N27 (18.50, 26.20). The other eight are post-fuse islands. |
| 8 | ADIO1–8. West pins have a B.Cu exit to y=73 and, for ADIO6/ADIO8, a bus at y≥80. The driver copper is north of the pour neck at y≈76–78. A track across that neck isolates GND, so the eight J1-to-driver lines stay open. |
| 3 | SENSOR_5V. R201.1, R205.1, R206.1 at y=56.20. R202 is tied. Pad centers other than R202 are not a legal via. |
| 1 | IGN_SW. J1.4 (34.30, 46.50) to R1.1 (55.175, 18.50). |
| 1 | IN_AUX4. M1000.S10 (32.70, 65.70) to C40.1 (96.825, 32.20). |
| 1 | IN_RES2. C107.1 (89.225, 54.30) to the B.Cu track at (88.00, 53.20). The 0603 neighborhood has no same-layer exit. |
| 1 | OUT_PWM8. M1000.E28 (44.00, 49.60) to the B.Cu track at (90.05, 47.85). |

No gerbers. 51 unconnected is more than the fuse gap plus the 13 keepout pairs.

IGN_SW still cannot leave J1.4. On F.Cu the pin stops at the SENSOR_5V run y=43.60, and the pocket north of that run stops on the PWR_OUT3/PWR_OUT4 copper at y≈37. On B.Cu the north row of M1000 (y≈26.4) and the driver wall at x≈44 close the other way around. IN_RES2 is a 0.60 mm channel between IN_O2S2 (y=54.00) and OUT_PWM2 (y=54.80); a via needs 0.90 mm, and a jog of either track does not both clear and still reach the B.Cu stub at y=53.20. IN_AUX4 on B.Cu reaches about x=58 after 80k cells and has not found the copper at (96.8, 32.2). OUT_PWM8 on F.Cu is a slot along the keepout edge, x=43.6–45.2, y=49.3–64.4, and the B.Cu side of that slot drains in a few hundred cells.

## Previous commit — carrier ratsnest on the 109×98 board

Does not move the outline, AUX origin, EMI split, bobbins, or any footprint. `scripts/cut_crossings_sexp.py` was not replayed. No SENSOR_GND pour. F1 is not bridged. No gerbers: the leftover is still more than the fuse gap plus the M1000 keepout.

[F.Cu / B.Cu overview](scripts/copper_fill_overview.png) — gold tracks are `PWR_OUT1–4`. [Exposed HP copper](scripts/hp_mask_openings.png) — gold is F.Cu, red is the F.Mask opening. Mask drawings on those nets stayed at **358**. Openings were not covered.

`kicad-cli pcb drc` **8.0.9**, `--severity-error`, `--units mm`. Report: [scripts/drc_109.txt](scripts/drc_109.txt).

| Issue | PR #14 (109×98) | After this pass |
|---|---:|---:|
| shorting_items | 0 | **0** |
| tracks_crossing | 0 | **0** |
| clearance | 0 | **0** |
| hole_near_hole | 0 | **0** |
| solder_mask_bridge | 0 | **0** |
| courtyards_overlap | 0 | **0** |
| padstack_invalid | 0 | **0** |
| unconnected_items | 129 | **64** |
| Pour verts inside M1000 keepout | 0 | **0** |
| SENSOR_GND pours | 0 | **0** |
| F1 bridged by pour | no | **no** |
| Footprints moved | — | **0** |
| Tracks / vias | 1008 / 121 | **1232 / 190** |
| F.Mask drawings on PWR_OUT | 358 | **358** |

### What closed

Local layer fixes (a via at the pad, 0.50/0.30) plus short ties inside 3 mm. GND carrier pads got one stitch each onto the B.Cu pour. C1.1 was strapped to the pre-fuse pour. Two post-fuse VBAT slivers were tied. PWR_OUT1–4 were already connected and were not retouched.

| Net group | Before | After |
|---|---:|---:|
| OUT_PWM / OUT_IO | 21 | **1** (OUT_PWM8 ↔ M1000.E28) |
| IN_* | 13 | **2** (IN_AUX4, IN_RES2) |
| ADIO1–8 | 25 | **8** (J1 pins only; driver side is tied) |
| GND | 53 | **38** |
| VBAT | 11 | **10** |
| SENSOR_5V | 5 | **4** |
| IGN_SW | 1 | **1** |

### Still open — geometry, not a search limit

| Count | What it is |
|---:|---|
| 38 | GND. **13** are M1000 keepout pad pairs (F.Cu vs B.Cu); the pour is not allowed in the keepout. The other **25** are carrier pads the B pour does not reach: the sense RC row (C101–C108, R101–R104, U11/U15/U16/U18 pin 1), R10/C10, R20/C20/U2.1, and the north stubs R2.2 / C1.2 / C2.2 / D1.2. Router notes: C105.2 (82.78, 54.30) is 3.08 mm from the pour cell (85.20, 52.40); R104.1 (77.17, 52.40) is 2.28 mm from (78.80, 50.80). A second pass was not run. |
| 10 | VBAT. One is the intentional fuse gap: pre-fuse zone anchor (68.5, 1.0) vs post-fuse (54.5, 27.5). One is M1000.N27 (18.50, 26.20), 36.33 mm from the post pour at (54.80, 27.60); the commit check rejected that path so it does not cross the fuse band (y=23.15–26.05). The other eight are post-fuse zone islands. DRC reports them all at the zone anchor (54.5, 27.5). C1.1 is connected. |
| 8 | ADIO1–8, the J1 pins only. Columns x=39.80 and x=42.30 sit east of the SENSOR_GND spine (B.Cu x=38.40, y=43.20–55.60, width 0.20). That spine blocks a west exit until y≈56. The band south of it (y=56.8–59.9, x=32–41) is 3.1 mm tall, but the pad maze east of the spine has one southbound opening. Routing ADIO1 through it (x=40.6–42.3, y=52.5–59.1) leaves ADIO2–7 with no path. All eight J1 pins were left open so that opening stays unused. |
| 4 | SENSOR_5V. The pull-up row is y=56.20, x=65.175 / 69.175 / 77.175 / 81.175 (R201, R202, R204, R205 pin 1), pitch 4.00 mm. Search stopped at 700k expansions on R201.1→R202.1 and on the track at (77.20, 56.20)→R205.1. |
| 1 | IGN_SW. J1.4 (34.30, 46.50) has no free B.Cu cell within 0.8 mm. A* does not reach the north shelf (42.0, 24.8) or the east alley (44.8, 32.0). R1.1 is (55.175, 18.50), on the far side of the same spine. |
| 1 | IN_AUX4. C40.1 (96.83, 32.20) to M1000.S10 (32.70, 65.70), 72.35 mm. Search stopped at 700k. |
| 1 | IN_RES2. C107.1 (89.22, 54.30) to the B.Cu tracks at y=53.20 (x=88.00 / 90.80). The neighborhood exhausts in 325 expansions: a same-layer exit does not clear SENSOR_5V and the neighboring 0603. |
| 1 | OUT_PWM8. Track end (90.00, 47.80) to M1000.E28 (44.00, 49.60), 46.04 mm. Search stopped at 700k. The east pad row is a 0.60 mm wall; the south slots are the long way around and were left for the ADIO pins. |

M1000 S-row passages that do reach y=76 on B.Cu, if a later pass needs them: x=18.9, 20.1, 21.3, 22.5, 23.7, 24.9, 26.1. Each waist is one 0.10 mm cell in a 0.60 mm copper gap, so one 0.15 mm track. x=45.6 is east of that wall and is not reachable from the pin field. J3 at (80, 86.5), radius 8 mm, pinches a south bus at x=82 down to y=73.0–74.2 (1.2 mm) plus a 0.4 mm sliver at y=78.0–78.4.

## Previous commit — 109×98 symmetric drivers

Edge.Cuts grew **5 mm on each axis**: **104×93 → 109×98 mm**. AUX origin is `(0, 98)` (bottom-left). This stays Razor-class. It does not return to 150×130. `scripts/cut_crossings_sexp.py` and the old 150×130 long-haul routers were not replayed. No SENSOR_GND pour. F1 is not bridged by a pour. No gerbers: the leftover ratsnest is more than the fuse gap plus the M1000 keepout.

[F.Cu / B.Cu overview](scripts/copper_fill_overview.png) — gold tracks are `PWR_OUT1–4`. [Exposed HP copper](scripts/hp_mask_openings.png) — gold is F.Cu, red is the F.Mask opening over that copper.

`kicad-cli pcb drc` **8.0.9**, `--severity-error`, `--units mm`. Report: [scripts/drc_109.txt](scripts/drc_109.txt).

| Issue | 104×93 main | After 109×98 |
|---|---:|---:|
| shorting_items | 0 | **0** |
| tracks_crossing | 0 | **0** |
| clearance | 0 | **0** |
| solder_mask_bridge | 0 | **0** |
| courtyards_overlap | 20 | **0** |
| padstack_invalid | 22 | **0** |
| unconnected_items | 60 | **129** |
| Outline | 104×93 | **109×98** |
| Pour verts inside M1000 keepout | — | **0** |
| SENSOR_GND pours | 0 | **0** |
| F1 bridged by pour | no | **no** |

### Outline and EMI split

| Item | Value |
|---|---|
| Edge.Cuts | **109 × 98 mm**, origin top-left, Y down |
| AUX origin | **(0, 98)** |
| Power-field centerline | vertical **x = 80** (drivers mirror about this line) |
| EMI wall | J1 vertical SuperSeal stays at **(48.8, 46.5) rot 90** |
| MCU | M1000 stays at **(2, 66) rot 0**, west of the wall |
| Bobbins | J2 VBAT+ **(80, 12)** north edge, J3 GND **(80, 86.5)** south edge. Not re-paired. Not on the M1000 side. |

### Symmetric driver map

Mirrored about x=80. West parts are rot 0 (OUT faces west, toward the connector). East parts are rot 180 (OUT faces east). North HP row feeds the north-end SuperSeal pins; south HP row feeds the south-end pins, so the same-layer paths do not have to cross.

| Ref | Net | Before (104×93) | After (109×98) |
|-----|-----|---|---|
| J2 | VBAT | (92, 11) rot 0 | **(80, 12) rot 0** |
| J3 | GND | (92, 82) rot 0 | **(80, 86.5) rot 0** |
| F1 | fuse | (58, 18) rot 0 | **(100, 15) rot −90** |
| U3 | PWR_OUT3 | (80, 53) rot 90 | **(66, 39.2) rot 0** |
| U4 | PWR_OUT4 | (96, 53) rot 90 | **(94, 39.2) rot 180** |
| U1 | PWR_OUT1 | (80, 40) rot −90 | **(66, 69.4) rot 0** |
| U2 | PWR_OUT2 | (96, 40) rot −90 | **(94, 69.4) rot 180** |
| U11–U14 | ADIO1–4 | y=69.5, x=52/60/68/76 rot 0 | **y=48.5**, x=67.1/75.7 rot **180**, x=84.3/92.9 rot **0** |
| U15–U18 | ADIO5–8 | y=77.5, same x, rot 0 | **y=60.1**, same x and rot rule |

Full before/after list (52 moved footprints): [scripts/layout_109_moves.txt](scripts/layout_109_moves.txt). J1 and M1000 did not move. Courtyard overlaps after the move: **0**.

### M1000 keepout

Hellen mega-mcu144 **0.7** (`hellen-one/modules/mega-mcu144/0.7`). Official keepout in the footprint is local `(0.1, −40) … (42.2, −0.1)`. On this board, with the anchor at (2, 66), that is **(2.1, 26.0)–(44.2, 65.9)**.

The embedded footprint had 22 inner pads (`In1.Cu` / `In2.Cu` stacked pairs, pad number `G`) saved with an empty layer set. Those are restored to the official inner layers, which clears the 22 `padstack_invalid` hits. A board-level rule area on F.Cu and B.Cu disallows copper pour and allows tracks, vias, and pads. After fill, **0 pour vertices** sit inside the keepout. Silk on the footprint already matched the 0.7 outline; it was not redrawn.

### Exposed HP output copper

Nets **PWR_OUT1, PWR_OUT2, PWR_OUT3, PWR_OUT4**. The solder-add copper is **F.Cu**. Every F.Cu segment on those nets has an **F.Mask** opening 0.08 mm narrower than the copper, so the mask does not reach the next net and the current path itself is bare. B.Cu hops are only where the module south-pad wall (0.6 mm gaps) or an existing signal track leaves no 0.20 mm F.Cu corridor; those hops are not mask-opened because there is no top copper there.

| Net | SuperSeal pins | F.Cu (exposed) | B.Cu hop |
|-----|---|---|---|
| PWR_OUT1 | J1.14 + J1.20 | 1.2 mm south trunk (55.6, 72.4)–(34.2, 72.4), plus 0.9 mm inside the field; pin fanout up to 2.4 mm | ~8 mm |
| PWR_OUT2 | J1.1 + J1.8 | pin/tab fanout to 2.4 mm and a 1.2 mm piece; the long perimeter run is 0.20–0.70 mm | ~17 mm |
| PWR_OUT3 | J1.7 + J1.13 | pin fanout to 2.4 mm; field run 0.50–0.70 mm, with ~120 mm still at 0.20 mm | ~13 mm |
| PWR_OUT4 | J1.19 + J1.26 | 0.9 mm east trunk along x=107.2 from the OUT pins to y=73.6; pin fanout to 2.4 mm; ~162 mm of the return path stays 0.20 mm | ~11 mm |

All four nets are connected (no `PWR_OUT*` ratsnest). The 0.20 mm lengths are the corridors that will not take a wider track at 0.20 mm clearance. Assemblers can load solder on the exposed F.Cu; the wide sections are the ones that add real copper area.

### Still open (no gerber zip)

| Count | What it is |
|---:|---|
| 53 | GND. About 14 are M1000 keepout pad pairs the pour is not allowed to fill. The rest are carrier stubs and module pads outside the punched pour. |
| 11 | VBAT. Ten are islands inside the post-fuse pour. One is C1.1, west of the pre-fuse finger. The pre-fuse / post-fuse split at F1 is intentional and is not bridged. D1.1 is strapped into the post-fuse pour only. |
| 25 | ADIO1–8. SuperSeal pins are still open; the 2.0 mm pads on a 2.5 mm pitch do not leave a 0.20 mm exit toward the drivers. |
| 21 | OUT_PWM / OUT_IO. M1000 east pads versus a track on the other copper layer. |
| 13 | IN_* sense and module pins, including C107.1 (`IN_RES2`). The old B.Cu stub from that F-only pad crossed `IN_O2S2` and did not actually connect the pad. It was removed. A same-layer exit does not clear SENSOR_5V and the neighboring 0603. |
| 5 | SENSOR_5V |
| 1 | IGN_SW |

## Previous commit — carrier ratsnest close (stacked on the DRC polish)

Does not undo the polish anchors (U3/U4 at +90°, J1 at x=48.8, D1 at (88, 24), sense RC at y=35.70). That pass held 104×93, J2 north / J3 south, M1000 west. No SENSOR_GND pour. F1 is not bridged. `scripts/cut_crossings_sexp.py` was not replayed. No gerbers.

[F.Cu / B.Cu overview](scripts/copper_fill_overview.png)

`kicad-cli pcb drc` **8.0.9**, `--severity-error`, `--units mm`. Counts below are from that run after the R1 courtyard experiment was reverted (it shorted IN_VIGN).

| Issue | Polish start | After this pass |
|---|---:|---:|
| shorting_items | 0 | **0** |
| tracks_crossing | 0 | **0** |
| clearance | 0 | **0** |
| unconnected_items | 75 | **60** |
| courtyards_overlap | 20 | **20** |
| padstack_invalid | 22 | **22** (M1000, left alone) |
| Tracks / vias | 931 / 210 | **1205 / 231** |

SENSOR_GND pours: **0**. Fuse still open (no VBAT segment touches both F1 pads). Placements of U3, U4, J1, D1, R10/C10/R20/C20, J2, J3, M1000, and F1 are unchanged. R1 was trial-nudged +0.37 mm in X to clear the F1 courtyard and moved back: the pad landed on the IN_VIGN track at y=23.2.

One via moved: SENSOR_GND at `(38.4, 55.6)` → `(38.4, 56.4)`, with the back-side spine extended to meet it. That via was the copper that sealed the only 0.20 mm corner out of J1 pin 21. The corner opens; the west corridor it feeds is still walled off from the ADIO driver copper (SENSOR_5V at y=61.7, IGN_SW at y=46.4, M1000 east pads 0.40 mm from the SuperSeal).

### What actually closed

| Net | Change |
|-----|---|
| IN_RES3 | U18.4 tied to the sense copper. |
| GND | Five carrier stubs joined (U2.1/C20.2, R20.1, R2.2, C2.2, one track stub). DRC GND count 25 → 24 after the earlier stitch had already taken 31 → 25; two carrier stubs remain. |
| SENSOR_5V | M1000 E38 and the R203/R204 pin-1 pair were already on the ratsnest that DRC reports; the new segments did not remove a DRC item. R206.1, R207.1, R208.1 and the x=2.0/2.6 stub are still open. |

### Still open (do not treat as fab-clean)

| Count | What it is |
|---:|---|
| 22 | M1000 `padstack_invalid`. Not edited. |
| 22 | M1000 GND front/back keepout openings. Not edited. |
| 20 | Courtyard overlaps. The only pair a ≤0.5 mm nudge can separate is F1/R1, and that nudge shorts IN_VIGN. U1/U2 vs the locked sense RC, and J2 vs D1, need more than 0.5 mm. |
| 10 | VBAT zone islands (HP slivers, B alley, ADIO tabs). A 0.22 mm local search from each island does not reach the post-fuse pour without entering the fuse keepout. |
| 1 | VBAT fuse gap. F.Cu strap into D1 vs the B.Cu hop from J2 to F1.1. Left open on purpose. |
| 2 | GND carrier stubs: F track `(57.15, 75.55)` vs via `(55.575, 80.8)`, and B `(79.2, 36.7)` vs F `(76.19, 60.65)`. |
| 4 | SENSOR_5V: R206.1, R207.1, R208.1, and the stub at x≈2 beside M1000. |
| 10 | ADIO1–8. J1 pins 15–17 and 21–24 are still open, plus R205.2 and R206.2. SuperSeal pads are 2.0 mm on a 2.5 mm column pitch (0.5 mm copper gap). A 0.20/0.20 rule cannot leave those pockets toward the drivers. |
| 4 | PWR_OUT1–4, one ratsnest each, across the M1000 north pad wall (0.2 mm gaps from x=2 to x=44.3). |
| 1 | IGN_SW, via `(43.6, 27.6)` vs track `(45.2, 27.6)`, same wall. |
| 6 | IS pins U12.4–U17.4. The inter-package slots are already full of OUT_PWM / ADIO / IN_AUX. IN_RES3 was the one slot with a clearance-legal 0.20 mm path. |

## Previous commit — surgical DRC polish (still not fab-clean)

Floorplan is the split-bobbin nest from PR #10. EMI split was not moved and the bobbins were not re-paired. `scripts/cut_crossings_sexp.py` and the other 150×130 routers were not replayed. Copper for the rotated HP/ADIO/SuperSeal nets was rebuilt in pcbnew from real pad coordinates (`scripts/drc_polish_east.py`).

[F.Cu / B.Cu overview](scripts/copper_fill_overview.png)

`kicad-cli pcb drc` **8.0.9**, `--severity-error`. Counts in [scripts/drc_zonefill.json](scripts/drc_zonefill.json) and [scripts/copper_status.txt](scripts/copper_status.txt).

| Issue | Main (PR #10 fill) | This polish |
|---|---:|---:|
| shorting_items | 177 | **0** |
| tracks_crossing | 131 | **0** |
| clearance | 110 | **0** |
| unconnected_items | 87 | **75** |
| solder_mask_bridge | 199 | **0** |
| via_diameter | 73 | **0** |
| drill_out_of_range | 73 | **0** |
| hole_near_hole | 17 | **0** |
| hole_clearance | 18 | **0** |
| courtyards_overlap | 23 | **20** |
| padstack_invalid | 22 | **22** (M1000, left alone) |
| Tracks / vias | 406 / 145 | **931 / 210** |

Pad-pad overlaps after the nudges below: **0**. SENSOR_GND pours: **0**. No VBAT segment touches both F1 pad coppers. A connectivity flood keeps J2 (pre-fuse) on a different island from F1.2 / the post-fuse, HP, and ADIO pours. The one VBAT ratsnest that remains is that fuse gap (F strap into D1 vs the B.Cu hop from J2 to F1.1).

### Placement nudges

Required to separate pad copper. J2, J3, M1000, U1, U2, and the ADIO anchors (U11–U18) did not move.

| Ref | Change |
|-----|---|
| U3, U4 | Rotation **−90° → +90°**. Anchors `(80, 53)` and `(96, 53)` unchanged. Tabs stay between the bobbins; pins face south so they no longer sit under the U1/U2 tabs. |
| R10, C10, R20, C20 | Y only, `32.00 → 35.70`. X unchanged. Sits in the gap between the north pin row and the tab. |
| D1 | `(80, 28) → (88, 24)`, rotation still 90°. |
| J1 | `(50.00, 46.50) → (48.80, 46.50)`, rotation still 90°. **1.2 mm west** so the SuperSeal PTH columns clear the M1000 east pad wall. |

### Leftovers (do not treat this as fab-clean)

| Count | What it is |
|---:|---|
| 22 | M1000 `padstack_invalid`. Module artifact. Not edited. |
| 22 | M1000 GND pad, front copper vs back copper. The module keepout punches the pour. |
| 20 | Courtyard overlaps (was 23). U3/U4 now face south; courtyards still meet the sense parts. |
| 10 | VBAT zone-to-zone. Split fill inside the HP zone (including one F island vs the B alley) and inside the ADIO zone. The ADIO pour is cut into per-driver islands by the pin-row tracks. U14's island is tied to the HP pour; the other ADIO tabs are local islands. |
| 1 | VBAT track-to-track. This is the fuse gap: the B.Cu hop from J2 to F1.1 versus the F.Cu strap from the post-fuse pour into D1. Do not connect them. |
| 9 | GND stitch stubs (track-track or track-via) that do not quite meet. |
| 9 | SENSOR_5V. Router joined 4 of 13 pads. Still open: R201–R208 pin 1 and M1000 E38. |
| 12 | ADIO1–8 landings. Mostly a SuperSeal pin (J1.15–17, J1.21–24) or a pull-up (R201.2, R205.2, R206.2) left 0.07–0.5 mm short, plus U13 pins 12–14. |
| 4 | PWR_OUT1–4, one ratsnest each, after the second pass deleted a shorting stub. |
| 1 | IGN_SW, via vs track. |
| 7 | IS pins U12.4–U18.4 (IN_MAP2/3, IN_O2S, IN_O2S2, IN_RES1–3) not tied to the local sense part. |

EN columns stay in the gap west of the M1000 east pads. No new via was dropped on those columns to chase the islands above.

## Previous commit — critical-net copper + zone fill on the split-bobbin floorplan

Mechanical placement from PR #9 is **unchanged** (54 footprints, 104×93 mm, J2 north / J3 south, vertical SuperSeal EMI wall, M1000 west). Old 150×130 / paired-M6 copper scripts were **not** reapplied. `scripts/cut_crossings_sexp.py` was **not** replayed.

[F.Cu / B.Cu zone-fill overview](scripts/copper_fill_overview.png)

| Item | Status |
|---|---|
| Tracks / vias | **406 / 145** (was 0 / 0 after PR #9 wipe) — +11 GND stitch vias, +6 M6 ring, +13 HP-tab thermal |
| Zones filled | **9** copper pours (GND B full-board, GND F around J3, VBAT F J2 / post-fuse / HP / ADIO, VBAT B J2 / post-fuse / HP alley). Keepout punches M1000. |
| Pad connect | **solid** on VBAT/GND (not thermal spokes) |
| HP VBAT F | `(73,32)–(103,64)` covers TO-263 tabs (north-facing). |
| VBAT B | J2 + post-fuse north islands + east alley `(86,32)–(103,61)` — **stops north of EN** (EN B south-hwys y≥66.7) |
| Fuse | J2 pour **split** from post-fuse pour (F1.1 is not in the island with F1.2 / J2) |
| EN/IS | **Track-connected** (union-find 0). EN exclusive B.Cu MCU–J1 gap columns + pin-south / south-of-J1 highways. IS local F (HP) / B-under-package (ADIO) + F.Cu staircase long-haul to S pads |
| PWR_OUT / ADIO | SuperSeal fanouts east of the pin field except J1 landings; ADIO F-hops the EN B band |
| GND | B.Cu full-board + F.Cu J3 island; carrier GND islands **11 → 0** after stitch+fill. **No SENSOR_GND bond** |
| SENSOR pour | **None** (not present; not added) |
| KiCad format | **20240108 / generator_version 8.0** |
| HELLCORE | **Not touched** |
| F1 | **ATO placeholder left** (Jeoff: do not block) |
| Footprints | **54** — placements not moved |

`kicad-cli pcb drc` **8.0.9**. See [scripts/drc_zonefill.json](scripts/drc_zonefill.json) and [scripts/unconnected_leftover.txt](scripts/unconnected_leftover.txt). **Not DRC-clean** — packed-east shorts/crossings remain for human polish.

## Previous commit — split M6 bobbins onto opposite power-field edges

Quintin: *“Split the Vbat & ground bobbins and place them on opposite sides of the board (not on the same side as the m1000) with the drivers inbetween.”*

Placement-only. Dual-bobbin `J2` replaced by `J2` VBAT+ `(92, 11)` and `J3` GND `(92, 82)`. Carrier tracks/vias/filled polygons wiped. That copper is **this** follow-up.

| Item | Status |
|---|---|
| Outline | **104 × 93 mm** |
| J2 / J3 | North VBAT+ / south GND, 71 mm N–S |
| Tracks / vias | **0 / 0** (intentionally stripped) |
| Zones | **7 unfilled outlines** |
| Footprints | **54** |

## Previous commit — zone fill + M6/HP stitch (104×93 EMI split)

Critical-net copper from the previous commit is **unchanged in plan** (no footprint moves, no 150×130 scripts, F1 ATO left). Pours are now **filled** in pcbnew 8.0.9. No SENSOR pour was added (none existed; SENSOR_GND stays off chassis).

That fill assumed **co-located** east M6 bobbins and was **invalidated** by this floorplan (copper stripped).

| Item | Status |
|---|---|
| Tracks / vias | **385 / 158** (was 385 / 136) — +10 M6 bobbin vias, +12 HP-tab thermal vias |
| Zones filled | **7** copper pours (GND B full-board, GND F M6−, VBAT F entry/HP/ADIO, VBAT B entry + U1/U2 tab island). Keepout punches M1000. |
| Pad connect | **solid** on VBAT/GND (not thermal spokes) |
| SENSOR pour | **None** (not present; not added) |
| KiCad format | **20240108 / generator_version 8.0** |
| HELLCORE | **Not touched** |
| Footprints | **53** |

## Previous commit — critical-net re-route on the 104×93 floorplan

Mechanical placement from the previous commit is **unchanged** (53 footprints, 104×93 mm, M6 bobbins, vertical SuperSeal EMI wall, M1000 keepout). Old 150×130 copper scripts were **not** reapplied.

| Item | Status |
|---|---|
| Tracks / vias | **385 / 136** (was 0 / 0 after the move) |
| EN/IS (HP1–4 + ADIO1–8) | **Connected** (exclusive EN B.Cu south-of-J1 highways + MCU-gap columns; IS local F + B.Cu east-skirt long-haul to S pads) |
| PWR_OUT1–4 / ADIO1–8 | **Connected** to SuperSeal (U1/U2 west of EN band; U3/U4 F-hop; ADIO 0.80 mm columns) |
| VBAT | F.Cu entry spine M6+→F1→C/D + B.Cu east alley to HP tabs; module N27 via **north corridor only** |
| GND | B.Cu full-board pour + sparse local F stubs/vias (no overcrowded east packs); **no SENSOR_GND bond**; M6− F island only |
| CAN / SENSOR_5V / SENSOR_GND / IGN_SW / IN_VIGN | **Connected** (north/east skirt; SENSOR_5V does not traverse the EN field) |
| USB | On-module only (USB-C is on mega-mcu144) — not a carrier leftover |
| J1 courtyard | **39.5 × 29.5 mm** (TE width 39 × catalog vertical D 29). Product-page **39 × 36.5 mm** shroud is on Cmts.User and **does not fit** between M1000 and U1 without moving HP. |
| Via packs (size+0.22) | **0** |
| KiCad format | **20240108 / generator_version 8.0** |
| HELLCORE | **Not touched** |
| F1 | **ATO placeholder left** (Jeoff: do not block) |
| Footprints | **53** |

`kicad-cli pcb drc` was **not available** in that agent VM. Geometric H–V scan (not KiCad DRC) still saw same-layer crossings in the packed east/south field. Zone fill + DRC is this follow-up.

See [scripts/unconnected_leftover.txt](scripts/unconnected_leftover.txt).

## Previous commit — mechanical / floorplan redesign (Quintin)

| Item | Status |
|---|---|
| Outline | **150 × 130 → 104 × 93 mm** (Link Razor class: enclosure 103.6 × 93.4) |
| AUX origin | **(0, 93)** — Edge.Cuts bottom-left; no negative board coords |
| J2 | **M6 bolt-through bobbins** (6.5 mm drill / 16 mm Cu / 25 mm pitch / via stitch) — previous 2.54 mm pin-header VBAT↔GND short is gone by construction |
| J1 | **Vertical** SuperSeal 26 (`6473418-1`), rotated 90° as EMI wall |
| EMI split | mega-mcu144 **west** of J1; power / PROFET / M6 **east** |
| M1000 | Keepout aligned to silk/pads (official 0.7 polygon); Value **`Module:mega-mcu144/0.7`** |
| Zones | **GND B.Cu** full-board + **VBAT F.Cu** entry/HP/ADIO islands (GND F only around M6−) + module pour keepout |
| KiCad format | **20240108 / generator_version 8.0** |
| HELLCORE | **Not touched** |
| Footprints | **53** (non-empty board) |

See [HARDWARE_BOM.md](HARDWARE_BOM.md) for kILIS / AmpsPerVolt TODOs.

## Floorplan (mm)

KiCad origin = Edge.Cuts top-left; Y down. AUX = bottom-left `(0, 93)`.

| Block | Placement |
|---|---|
| M1000 | West `(2, 66)` — 42.2 × 40 mm module, keepout on pads |
| J1 EMI wall | `(50, 46.5)` **rot 90°** — vertical SuperSeal between MCU and power |
| J2 VBAT+ M6 | North power-field edge `(92, 11)` — 16 mm Cu, **not** on the MCU west side |
| J3 GND M6 | South power-field edge `(92, 82)` — opposite J2; 71 mm N–S span |
| Power entry | F1 ATO placeholder `(58, 18)` + C1/C2 in the north pocket on the VBAT path; D1 `(80, 28)` |
| HP ×4 | East alley 2×2 @ `(80/96, 40/53)` rot 270° (tabs face north / VBAT) |
| ADIO ×8 | South of SuperSeal 2×4 @ `(52…76, 69.5/77.5)`, west of J3, **between** the bobbins in Y |

```
x=0                    x=45                 x=74                 x=104
+----------------------+--------------------+--------------------+
| mega-mcu144 (M1000)  | vertical SuperSeal | J2 VBAT+ M6 (north)|
| quiet / logic        | 26  EMI SPLIT      | HP PROFET          |
|                      |                    | ADIO  (between)    |
|                      |                    | J3 GND M6 (south)  |
+----------------------+--------------------+--------------------+
                              y=93
```

Bobbins are **not** paired on the east edge and **not** on the M1000 west side.

## Copper strategy (split-bobbin EMI split)

Prefer **zone fills for power/GND**; signal long-haul uses exclusive lanes around the SuperSeal (not through MCU west copper except EN/IS/CAN/SENSOR at the connector spine / north corridor).

1. **VBAT** — F.Cu J2 island `(83.5,1)–(103,22)` (pre-fuse) + post-fuse north `(66.5,1)–(82.5,24)` + HP tabs `(73,32)–(103,64)` + ADIO `(48,66)–(82,81)`; tracks J2→F1.1, F1.2→HP spine x=88; B.Cu matching north islands + east alley stopping at y=61
2. **GND** — B.Cu near-full board (module keepout punches M1000) + F.Cu island around J3 `(82,72)–(103,92)`; stitch vias at M6/HP/SMD
3. **SENSOR_GND** — stays off chassis; **no SENSOR pour**
4. **EN** — exclusive B.Cu MCU–J1 gap columns x=45.15…49.55 + HP pin-south band y≈56.6–63 + ADIO south-of-J1 Y
5. **IS** — local F HP / B-under-ADIO; F.Cu staircase south of ADIO (west of J3) to M1000 S pads
6. **PWR_OUT / ADIO** — stay east of the pin field except J1 landings; F-hop the EN B band

FreeRouting / dense meshes still skipped (mega-mcu144 padstacks).

## Unconnected / routing status

| Metric | Floorplan PR #9 | This copper + fill |
|---|---|---|
| DRC shorts | not claimed (0 tracks) | **177** (packed east: PWR_OUT3/4, IN_AUX vs PWR_OUT, 10× GND↔VBAT). Old 25 mm M6 GND-vs-VBAT-spine short is **gone** |
| DRC crossings | ~0 (no tracks) | **131** kicad-cli / **387** geometric H–V |
| DRC unconnected | Up (copper stripped) | **87**. VBAT **3** (fuse gap + ADIO island). GND **40** (mostly M1000 keepout). EN/IS union-find **0**; kicad-cli still lists 1-island leftovers on OUT_PWM1–4 / IN_AUX / ADIO |
| EN/IS unconnected | Open | **0** (track-connected) |
| Tracks / vias | 0 / 0 | **406 / 145** |
| Zones filled | 7 unfilled outlines | **9** filled + M1000 keepout |
| Footprints / outline | 54 / 104×93 | 54 / 104×93 |

## DRC notes

`kicad-cli pcb drc` **8.0.9** on the filled board (`scripts/drc_zonefill.json`):

| Issue | Notes |
|---|---|
| shorting_items | **177**. Dominant: packed HP/ADIO east (PWR_OUT3↔4, IN_AUX↔PWR_OUT, GND↔VBAT near tabs). Not a 25 mm dual-bobbin pad clash. Human polish. |
| tracks_crossing | **131** kicad-cli / **387** geometric H–V. Human polish in HP/ADIO south. Do **not** replay `cut_crossings_sexp.py`. |
| unconnected_items | **87**. Carrier GND union-find **0** after pour. kicad-cli GND 40 ≈ M1000 keepout + a few SMD via misses. SENSOR_GND ×3 is the dedicated island. |
| solder_mask_bridge | **199**. M6 16 mm pads / module padstack. |
| J1 courtyard | Closed `fp_rect`. **Width 39 mm** (TE). **Length 29 mm** (catalog vertical D). Product-page **36.5 mm** shroud is Cmts.User only. |
| M1000 padstack | Module artifact (`padstack_invalid` 22); ignore for carrier DRC. Keepout outline matches silk `(0.1,0)…(42.2,−40)`. |
| M6 pads | 16 mm Cu on opposite edges — old “GND pad vs VBAT spine” short from the 25 mm pair is gone by construction |

## Schematic sheets

| Sheet | File | Contents |
|---|---|---|
| Root | `pdmrazora.kicad_sch` | SuperSeal 26 **vertical** + **split M6 bobbins** (J2 VBAT+ / J3 GND) + power entry + IGN_SW divider |
| MM144 | `MM144.kicad_sch` | mega-mcu144 0.7 + PINMAP globals |
| HP | `HP.kicad_sch` | HP1–4 BTS50010-1TAD + IS sense |
| ADIO | `ADIO.kicad_sch` | ADIO1–8 BTS7004-1EPP + IS/PU |

## Fab-blocker checklist

| # | Blocker | Status |
|---|---|---|
| 1 | Real AMP SuperSeal 26 footprint | **Done** (vertical 6473418-1; same pin numbers as CONNECTOR.md) |
| 2 | Final PROFET PNs + sense networks | **Done** |
| 3 | Power entry + IGN_SW divider | **Done** |
| 4 | Place HP/ADIO footprints on PCB | **Done** (re-nested between split M6 bobbins on 104×93) |
| 5 | create-board / copper finish | **Partial** — shorts and crossings are 0; unconnected 75, courtyards 20, M1000 padstack 22. Not fab-clean. No gerbers. |

## Remaining polish (human)

- Not fab-clean. Shorts and crossings are 0. What remains is the leftover table at the top: SENSOR_5V, ADIO SuperSeal landings, IS pins U12–U18 pin 4, split ADIO/HP VBAT pour islands, GND stitch stubs, courtyards, M1000 padstack.
- Do **not** replay `scripts/cut_crossings_sexp.py` (150×130) and do **not** bridge F1.1 to F1.2.
- SENSOR_GND stays off chassis GND (no SENSOR pour).
- TE **6473418-1**: courtyard is 39×29 mm (fits the EMI wall). Product-page 39×36.5 mm shroud **does not fit** without nudging HP/M1000 — verify against the TE drawing before fab
- M6 hardware: two independent copper bobbins + M6×8 button-head, 4 N·m, 25 mm² cable (CONNECTOR.md) — north VBAT / south GND
- ADIO/HP packing between the bobbins is still tight — nudge before fab
- F1 remains the ATO blade placeholder (now on the north VBAT path; J2 pour split so the fuse is not poured around)
- Ideal-diode / reverse-protect controller
- Discrete FET for ADIO PU hard-enable (`OUT_IO9–13`, `IO1–3`)
- ADIO V-sense divider values (`IN_TPS` / `IN_PPS` / …)

## Scripts

- `scripts/drc_polish_east.py` — **this commit**: placement nudges, fuse-safe VBAT straps, grid re-route, kicad-cli 8 DRC. Do not point it at a 150×130 board.
- `scripts/route_split_bobbins.py` — sexp critical-net router for the J2-north / J3-south nest (rotation used there does not match KiCad; do not re-run on this copper)
- `scripts/fill_zones_split.py` — **this commit**: pcbnew 8 ZONE_FILLER, solid VBAT/GND pours, M6/HP via stitch, kicad-cli DRC
- `scripts/drc_zonefill.json` — compact DRC counts from kicad-cli 8.0.9
- `scripts/unconnected_leftover.txt` — pad-island leftover list
- `scripts/copper_fill_overview.png` — F/B pour overview
- `scripts/split_bobbins_floorplan.py` — PR #9 placement (do not re-run blindly; wipes copper)
- `scripts/layout_positions.txt` — current footprint XY
- `scripts/floorplan_fcu_overview.png` — F.Cu pad/outline overview of the nest
- `scripts/fill_zones_104x93.py` / `scripts/route_critical_nets.py` — paired-M6 104×93 copper; do not re-run on this nest
- `scripts/layout_redesign.py` — original 104×93 shrink + dual-bobbin J2
- Older copper scripts (`cut_crossings_sexp.py`, `route_is_longhaul_thin_en.py`, …) target the **old** 150×130 nest and must not be re-applied blindly

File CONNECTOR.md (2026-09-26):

# PowerCore — Link Razor-compatible connector pinout (match exactly)

PowerCore uses the same AMP SuperSeal 1.0 26-pin (Link “Connector C”) and M6 main-power arrangement as the Link ECU **Razor PDM**, so existing Razor looms plug in.

Sources: Link PDM Quick Start Guide; Link KB inputs/outputs.

## Main power (not on the 26-pin)

| Terminal | Function | Notes |
|---|---|---|
| M6 + | Battery positive | 25 mm² / 4 AWG recommended; torque 4 Nm. PCB: **J2**, single bolt-through bobbin on the **north** power-field edge. Plated 6.5 mm hole / 16 mm Cu. Independent of M6− (no 25 mm dual-bobbin footprint). |
| M6 − | Battery negative / power ground | PCB: **J3**, same mechanical, **south** power-field edge. HP/ADIO drivers sit between J2 and J3. |

## 26-pin AMP SuperSeal 1.0 (Link “Connector C”)

**Board header PN:** TE Connectivity **6473418-1** (SuperSeal 1.0, 26-pos, **vertical**, Au, mounting holes). Alternate vertical Au without mounting holes: **6437288-6**. Footprint `pdmrazora:TE_6473418-1_SuperSeal26_Vertical` uses the same 3.0 mm 4-row PCB pattern as TE drawing 9-1437287-8 / obsolete 6473423-1 / previous RA **9-6437287-8**, so loom pin numbers are unchanged.

Viewed looking into wire side of loom connector (or into PDM header).

| Pin | Signal | Notes |
|----:|---|---|
| 1 | PWR OUT 2 | High-power; parallel with pin 8; 16 AWG / 1.25 mm² |
| 2 | N/C | |
| 3 | CAN H | |
| 4 | IGN SW | Switched +12 V ignition sense / key-on |
| 5 | SENSOR 5V | ≤50 mA; not tied internally to pin 11 |
| 6 | SENSOR GND | **Do not** bond to chassis |
| 7 | PWR OUT 3 | Parallel with pin 13 |
| 8 | PWR OUT 2 | Parallel with pin 1 |
| 9 | N/C | |
| 10 | CAN L | |
| 11 | SENSOR 5V | Second 5 V pin; spread loads |
| 12 | SENSOR GND | **Do not** bond to chassis |
| 13 | PWR OUT 3 | Parallel with pin 7 |
| 14 | PWR OUT 1 | Parallel with pin 20 |
| 15 | A/D I/O 2 | ADIO2 |
| 16 | A/D I/O 4 | ADIO4 |
| 17 | A/D I/O 6 | ADIO6 |
| 18 | A/D I/O 8 | ADIO8 |
| 19 | PWR OUT 4 | Parallel with pin 26 |
| 20 | PWR OUT 1 | Parallel with pin 14 |
| 21 | A/D I/O 1 | ADIO1 |
| 22 | A/D I/O 3 | ADIO3 |
| 23 | A/D I/O 5 | ADIO5 |
| 24 | A/D I/O 7 | ADIO7 |
| 25 | N/C | |
| 26 | PWR OUT 4 | Parallel with pin 19 |

Pins **2** and **9** stay N/C on the loom: no harness wire is added and the signal column above does not change. On the PCB those unused pads are tied to ADIO2 so the pour can leave between the same-net holes. Pin **25** stays N/C and is not tied.

A loom break that would move ADIO4, ADIO6, or ADIO8 onto other SuperSeal pins (including pin 25 and the signal pins 3, 4, 5, 6, 10, 11, 12) does not open a continuous ≥3.47 mm neck at 1 oz. That reassignment was not applied. The table above is still the Link Razor map. See BOARD.md.

Also on enclosure (not SuperSeal): **USB-C** for config.

## PowerCore carrier mapping intent

| Razor loom | PowerCore nets |
|---|---|
| M6 + / − | VBAT / GND power entry (fusing, TVS) |
| PWR OUT 1..4 (paired pins) | HP1..HP4 dual SuperSeal feeds from PROFET outs. On the 109×98 board the four PROFET outputs (`PWR_OUT1–4`) are exposed F.Cu from the BTS50010 pads toward J1, with an F.Mask opening over that copper so solder can be added for current. A short B.Cu neck crosses the mega-mcu144 south pad wall. Pin pairs stay split: 14+20, 1+8, 7+13, 19+26. |
| ADIO 1..8 | ADIO front-end I/O |
| CAN H/L | Module CANH/CANL |
| IGN SW | Key sense → divider → `IN_VIGN` path (and/or digital) |
| SENSOR 5V ×2 | `V5A_SWITCHABLE` via PWR_EN |
| SENSOR GND ×2 | AGND / sensor ground island |
| USB-C | Module USB |

MCU module: **mega-mcu144** rev ≥ 0.7. Internal MM144 net assignment: see PINMAP.md.

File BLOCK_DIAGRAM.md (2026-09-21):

# PowerCore rev 1 carrier block diagram

```mermaid
flowchart TB
  subgraph Power["Power entry"]
    VBAT[VBAT / main terminals]
    TVS[TVS + reverse + input fuse]
    VSENSE[VBATT sense divider]
    VBAT --> TVS --> RAILS
    TVS --> VSENSE
  end

  subgraph RAILS["Rails"]
    VLOAD[VLOAD switched / fused feed]
    VLOGIC[Module logic from MM144]
    V5[5V sensor switched via PWR_EN]
  end

  subgraph HP["High-power x4"]
    HPDRV[PROFET / half-bridge stage]
    HPIS[IS current sense]
    HPOUT[HP1..HP4 dual SuperSeal pins]
    VLOAD --> HPDRV --> HPOUT
    HPDRV --> HPIS
  end

  subgraph ADIO["ADIO x8"]
    ADIODRV[8A high-side]
    ADIOMUX[Pin mux: out / ain / din]
    ADIOPU[Soft 4k7 pull-up]
    ADIOS[Sense V and/or I]
    ADIOCONN[ADIO1..ADIO8]
    VLOAD --> ADIODRV --> ADIOMUX --> ADIOCONN
    ADIOPU --> ADIOMUX
    ADIOMUX --> ADIOS
  end

  subgraph MCU["mega-mcu144 STM32F767"]
    GPIO[EN / PWM / DIR / PU GPIO]
    ADC[ADC bank]
    USB[USB-C]
    CAN[CAN]
  end

  GPIO --> HPDRV
  GPIO --> ADIODRV
  GPIO --> ADIOPU
  HPIS --> ADC
  ADIOS --> ADC
  VSENSE --> ADC

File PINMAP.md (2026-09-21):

# PowerCore pin map — mega-mcu144 (H144 / STM32F767ZI)

Symbols from `firmware/config/boards/hellen_meta.h` (`H144_*`).  
Edge nets on the KiCad symbol are unprefixed (`OUT_PWM1`, `IN_VIGN`, …).

**Module:** [mega-mcu144](https://github.com/andreika-git/hellen-one/tree/master/modules/mega-mcu144) rev ≥ 0.4 (prefer **0.7**).  
**Must drive** `OUT_PWR_EN` / `H144_GP8` (PE10) high so switched analogs / 5 V / SD come up.

## High-power outputs (4)

| Chan | Enable / PWM | Edge | H144 / STM32 | DIR (optional) | Edge | Current sense | Edge / ADC |
|---|---|---|---|---|---|---|---|
| HP1 | EN | OUT_PWM1 | `H144_OUT_PWM1` PD13 | DIR | OUT_IO1 `H144_OUT_IO1` PD3 | IS | IN_AUX1 `H144_IN_AUX1_ANALOG` EFI_ADC_8 |
| HP2 | EN | OUT_PWM2 | `H144_OUT_PWM2` PC6 | DIR | OUT_IO2 `H144_OUT_IO2` PA9 | IS | IN_AUX2 `H144_IN_AUX2_ANALOG` EFI_ADC_14 |
| HP3 | EN | OUT_PWM3 | `H144_OUT_PWM3` PC7 | DIR | OUT_IO3 `H144_OUT_IO3` PG14 | IS | IN_AUX3 (verify AUX3/4 flip on 0.7) EFI_ADC_7 |
| HP4 | EN | OUT_PWM4 | `H144_OUT_PWM4` PC8 | DIR | OUT_IO4 `H144_OUT_IO4` PG5 | IS | IN_AUX4 EFI_ADC_15 |

## ADIO (8) — separate current + voltage sense

| Chan | EN edge | H144 EN | Current (I) | Voltage (V) | Pull-up EN |
|---|---|---|---|---|---|
| ADIO1 | OUT_PWM5 | `H144_OUT_PWM5` PC9 | IN_MAP1 EFI_ADC_10 | IN_TPS EFI_ADC_4 | OUT_IO9 `H144_OUT_IO9` PG13 |
| ADIO2 | OUT_PWM6 | `H144_OUT_PWM6` PD14 | IN_MAP2 EFI_ADC_11 | IN_PPS EFI_ADC_3 | OUT_IO10 `H144_OUT_IO10` PG12 |
| ADIO3 | OUT_PWM7 | `H144_OUT_PWM7` PD15 | IN_MAP3 EFI_ADC_2 | IN_TPS2 mux EFI_ADC_20 | OUT_IO11 `H144_OUT_IO11` PG2 |
| ADIO4 | OUT_PWM8 | `H144_OUT_PWM8` PD12 | IN_O2S EFI_ADC_0 | IN_PPS2 mux EFI_ADC_19 | OUT_IO12 `H144_OUT_IO12` PA8 |
| ADIO5 | OUT_IO5 | `H144_OUT_IO5` PD2 | IN_O2S2 EFI_ADC_1 | IN_CLT EFI_ADC_12 | OUT_IO13 `H144_OUT_IO13` PG6 |
| ADIO6 | OUT_IO6 | `H144_OUT_IO6` PG11 | IN_RES1 PF9 | IN_IAT EFI_ADC_13 | IO1 `H144_GP_IO1` PD4 |
| ADIO7 | OUT_IO7 | `H144_OUT_IO7` PG3 | IN_RES2 PF10 | IN_AT1 mux EFI_ADC_29 | IO2 `H144_GP_IO2` PD7 |
| ADIO8 | OUT_IO8 | `H144_OUT_IO8` PG4 | IN_RES3 PF8 | IN_AT2 mux EFI_ADC_28 | IO3 `H144_GP_IO3` PG10 |

Muxed V channels (TPS2/PPS2/AT1/AT2) need `ADC_MUX_PIN` = PF2 (`H144_GP9`) and PWR_EN already high.

Freq / digital capture for ADIO5–8 when used as inputs: `H144_IN_D_1`–`4` (PE12–15) and/or digital companions on CLT/IAT/AUX.

## System

| Function | Edge | H144 / STM32 |
|---|---|---|
| USB | USBID / USBM / USBP | PA10 / PA11 / PA12 |
| CAN | CANH / CANL | PD0 / PD1 (on-module xcvr) |
| VBATT sense | IN_VIGN | `H144_IN_VBATT` PA5 EFI_ADC_5 |
| Board temp | IN_SENS1 | PF3 (ADC3 path) |
| PWR_EN | OUT_PWR_EN | `H144_GP8` PE10 |
| LEDs | LED_* | PG0 / PG1 / PE7 / PE8 |

## Spares (rev 1.1+)

`OUT_INJ1`–`8`, `IGN1`–`8`, `IO4`–`7`, `IN_CRANK`/`CAM`/`VSS`, `IN_SENS2`–`4`, SPI2/3, I2C, UART2/8 — FAULT lines, second CAN, extra digitals.

## Firmware notes

- Firmware overlay: [fw-powercore](https://github.com/quintinbannink42/fw-powercore) (`SHORT_BOARD_NAME=powercore`).
- Prefer template [fw-custom-hellen144-f4](https://github.com/rusefi/fw-custom-hellen144-f4) (F7 CPU in our `meta-info.env`) or Hellen boards using `hellen-common144.mk` / `hellen-common-mega144.mk`.
- Hardware frame: [hellen-example](https://github.com/rusefi/hellen-example).
- `protected_gpio` covers 8 channels: map **HP1–4 + ADIO1–4** first; ADIO5–8 protection is TODO / second bank.
- Confirm IN_AUX3/AUX4 orientation against mega-mcu144 **0.7** schematic before PCB.

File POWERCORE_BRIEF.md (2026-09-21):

# PowerCore — product brief

**Product:** PowerCore (standalone automotive power distribution module)  
**Hardware repo:** `hellen-pdm-razor` (legacy GitHub path; **product name is PowerCore**)  
**KiCad stem:** `pdmrazora` (hellen-one: no dashes/underscores — **do not rename**)  
**Firmware:** [fw-powercore](https://github.com/quintinbannink42/fw-powercore)  
**MCU module:** Hellen mega-mcu144 (STM32F767), rev ≥ 0.7  
**Loom / connector:** Link **Razor PDM**-compatible AMP SuperSeal 1.0 26-pin (Link “Connector C”) + M6 main power  

**Not:** [HELLCORE](https://github.com/quintinbannink42/HELLCORE), Micro Core, or an engine ECU.

Former working names (docs/history only): `hellen-pdm-razor`, Hellen Razor-class PDM.

## What it is

PowerCore is a Hellen-One **carrier** that distributes battery power through programmable high-side channels, with TunerStudio as a **PDM** environment (outputs, current, trips, CAN), not a full ECU page set.

Rev 1 I/O:

- 4× high-power (25 A continuous / 80 A peak class)
- 8× ADIO (8 A high-side, analog/digital in, software pull-ups)
- USB + CAN; electronic-fuse behaviour in firmware
- Drop-in **connector and loom compatibility** with the Link ECU Razor PDM SuperSeal pinout

## Identity tokens (do not mix)

| Layer | Token | Notes |
|---|---|---|
| Product | **PowerCore** | User-facing name |
| GitHub hardware | `hellen-pdm-razor` | Legacy repo path; clone URL unchanged |
| KiCad / hellen-one | `pdmrazora` | `BOARD_PREFIX=pdm` `BOARD_SUFFIX=razor` `BOARD_REVISION=a` |
| Firmware | `powercore` | `SHORT_BOARD_NAME` / `FIRMWARE_ID` in fw-powercore |

## Hardware ownership

This repo owns the Hellen-One frame, SuperSeal header, PROFET stages, and pinout docs. Firmware lives in **fw-powercore**. Do not invent pins: [PINMAP.md](PINMAP.md), [CONNECTOR.md](CONNECTOR.md), [REV1_SPEC.md](REV1_SPEC.md), [HARDWARE_BOM.md](HARDWARE_BOM.md).

## Out of scope

- Renaming KiCad files away from `pdmrazora`
- Mixing with HELLCORE or Micro Core streams
- Sealed Link-style CNC housing / “PDM Link” clone UI (rev 1 non-goal)

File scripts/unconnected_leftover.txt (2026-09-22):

# Leftover after ADIO-rest attempt (still 46)

kicad-cli 8.0.9, severity-error, units mm. Unconnected **46** (unchanged from PR #17).
Shorts, crossings, clearance, hole-to-hole, solder-mask bridge, courtyards, padstack: 0.
F1 not bridged. SENSOR_GND pours 0. Keepout pour vertices 0.
F.Mask openings on PWR_OUT stayed at 358. No footprint moves.
Tracks / vias 1297 / 207. VBAT filled islands stay 33.

Serious attempt to land ADIO1/2/3/4/5/7/8 with the ADIO6 pour-keepout pattern.
No copper kept: every close of an ADIO ratsnest opened ≥1 GND (sometimes VBAT) island.
See `scripts/adio_rest_blockers.txt` for mm measurements.

## Still open — 46

- GND 23. 11 are M1000 keepout F/B pairs. One is the keepout pair between
  (44.20, 65.00) and (44.20, 59.35). One is a B.Cu zone fragment anchored at
  (0.8, 0.8). Still open on pads: C101.2, C102.2, R101.1, U15.1, U16.1, U18.1.
- VBAT 10. Fuse gap (68.5, 1.0) vs (54.5, 27.5), M1000.N27 (18.50, 26.20),
  and eight post-fuse islands. Not bridged.
- ADIO 7. ADIO1, ADIO2, ADIO3, ADIO4, ADIO5, ADIO7, ADIO8. ADIO6 only.
  - ADIO2: bus to (70.8, 80.6) and spine to y=62 clear; F landing needs y≈52 through SENSOR_5V/OUT_IO*/IN_* walls.
  - ADIO4: IN_RES3 via (23.2, 76.0) is 0.025 mm too close to column x=23.7; after a trial via nudge, bus dies at x≈72 on the ADIO6/J3 wall.
  - ADIO8: east-skirt BFS reaches U18 but cuts a B-only GND pocket (~98,54)–(103,62) with no F pour to stitch.
  - ADIO5: pin→(64.2, 60.8) path exists; keepout+stitch closes ADIO5 but VBAT islands 33→34.
  - ADIO1/3/7: no BFS to driver copper within 400k expansions.
- SENSOR_5V 3. R201.1 and R205.1 (R205 is in two edges).
- IGN_SW J1.4 (34.30, 46.50) ↔ R1.1 (55.175, 18.50).
- IN_AUX4 M1000.S10 (32.70, 65.70) ↔ C40.1 (96.825, 32.20).
- OUT_PWM8 M1000.E28 (44.00, 49.60) ↔ B.Cu (90.00, 47.80).

No gerbers. Leftover is more than the fuse gap plus the M1000 keepout.

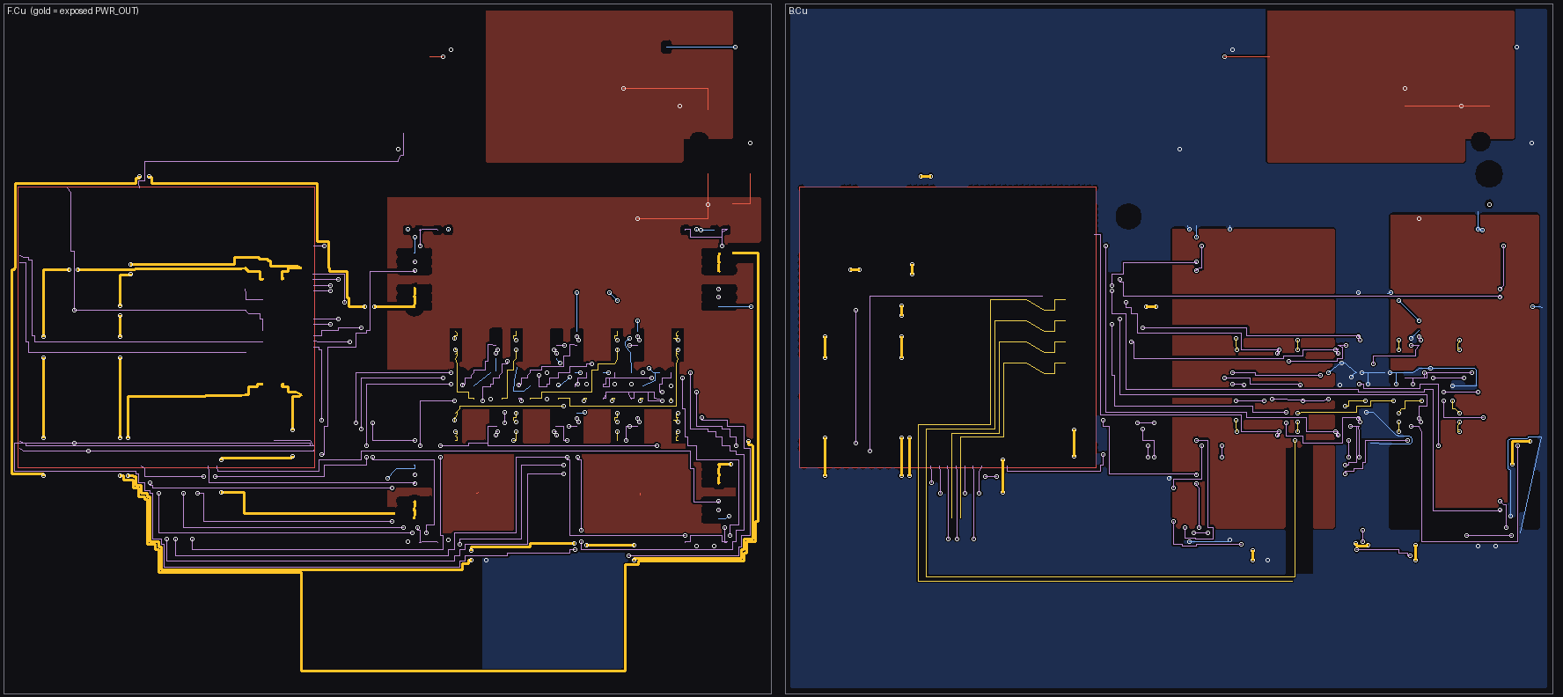
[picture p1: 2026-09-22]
scripts/copper_fill_overview.png

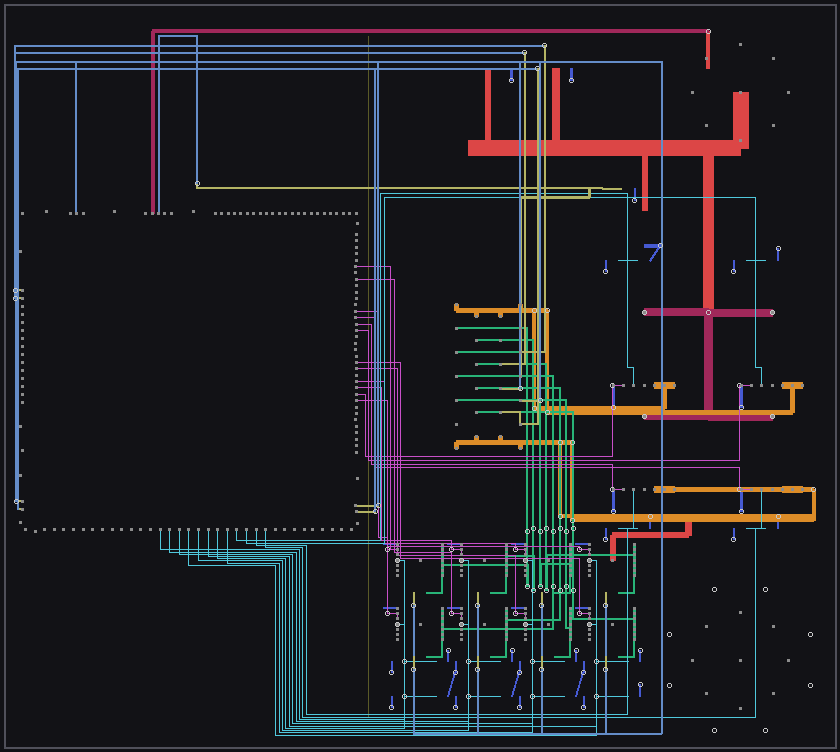
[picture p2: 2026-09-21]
scripts/copper_overview.png

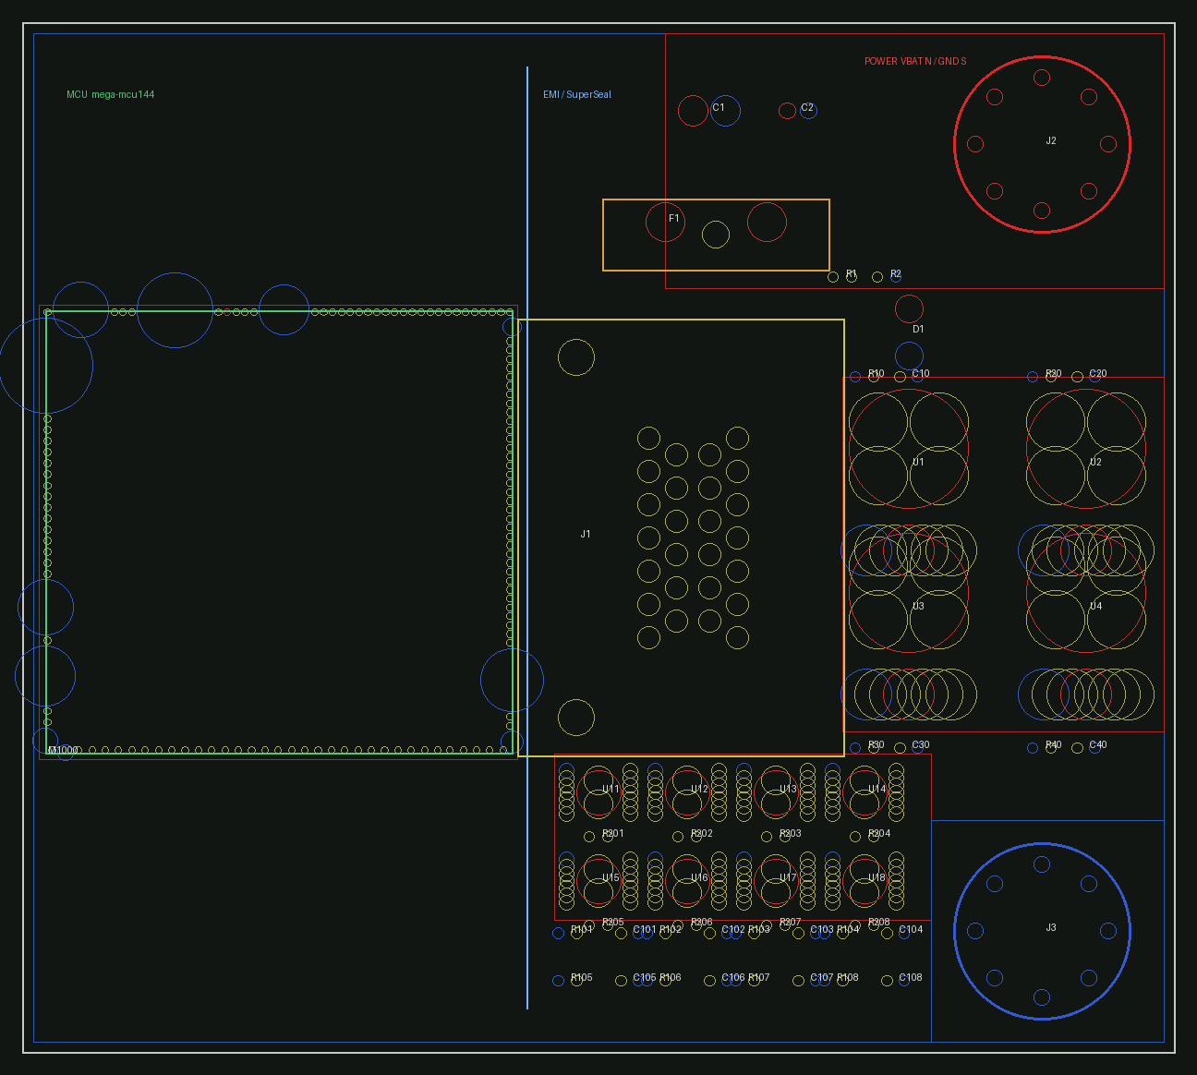
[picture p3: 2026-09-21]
scripts/floorplan_fcu_overview.png

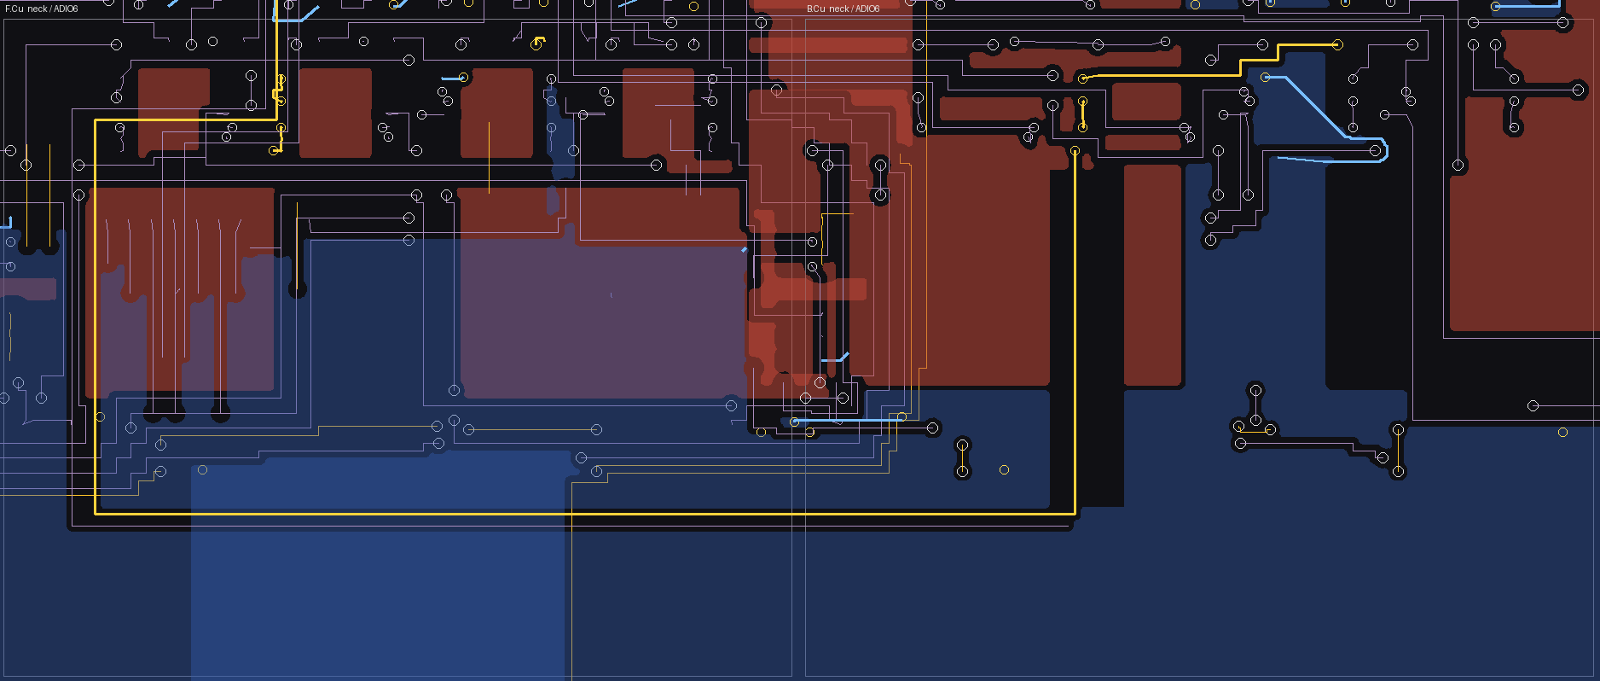
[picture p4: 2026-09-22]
scripts/neck_adio6.png

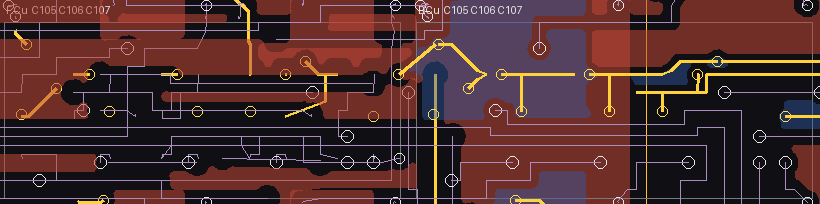
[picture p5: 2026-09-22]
scripts/in_res2_c105.png

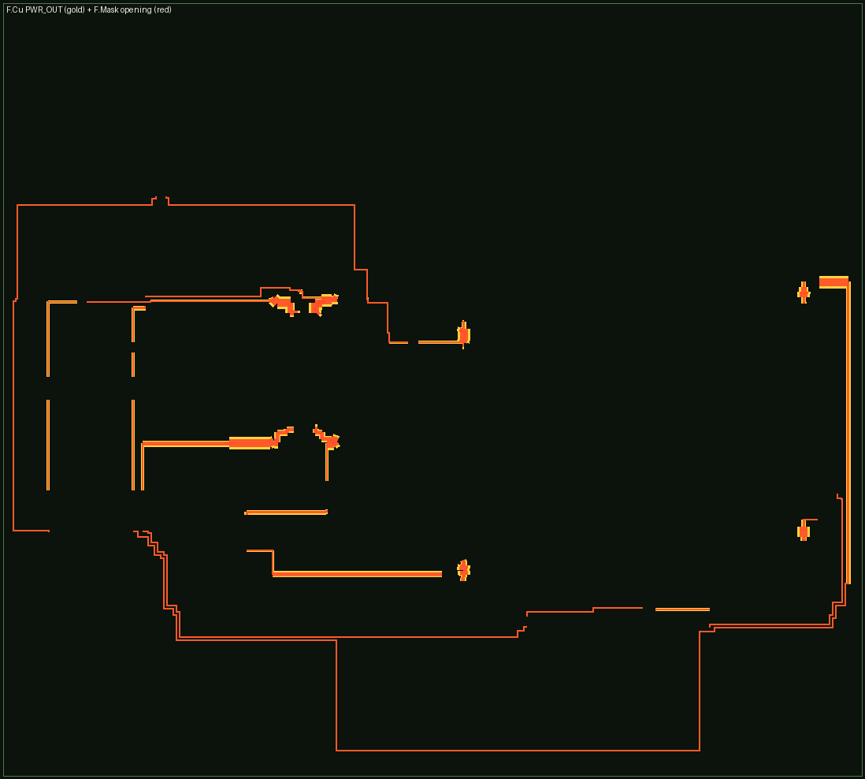
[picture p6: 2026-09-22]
scripts/hp_mask_openings.png

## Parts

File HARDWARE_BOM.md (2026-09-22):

# Hardware BOM / sense assumptions — PowerCore (`pdmrazora` rev a)

Production-intent parts chosen for Link Razor-compatible ratings. Firmware must still calibrate `AmpsPerVolt`.

## Connector

| Ref | PN | Notes |
|-----|-----|---|
| J1 | **TE Connectivity 6473418-1** | AMP SuperSeal 1.0, 26-way, **vertical**, Au. Mating loom: SuperSeal 1.0 26S keying 1 (Link “Connector C”). Alternate: **6437288-6** (vertical Au, no mounting holes). Footprint: `pdmrazora:TE_6473418-1_SuperSeal26_Vertical` (same 3 mm / 4-row pattern as 9-6437287-8 / 9-1437287-8; pin numbers = TE / [CONNECTOR.md](CONNECTOR.md)). Previous RA 9-6437287-8 leftover in `pdmrazora.pretty` is unused. |

## High-power (HP1–4)

| Ref | PN | Package | Why |
|-----|-----|---|-----|
| U1–U4 | **Infineon BTS50010-1TAD** | PG-TO-263-7 (`TO-263-7_TabPin4`) | 1.0 mΩ Power PROFET™ 12 V, IL(NOM) **40–48 A** @ 85 °C, ICL ≥ **150 A** — covers Razor **25 A continuous / 80 A peak** with margin. Automotive VS 3.2–28 V, ISENSE diagnosis. |

### HP current sense

| Param | Value | Notes |
|---|---|---|
| kILIS (typ) | **≈ 52100** | Infineon `dkILIS` / kILIS at IL(NOM); treat as starting point |
| RIS | **2.7 kΩ** (R10/R20/R30/R40) | IIS = IL / kILIS → Vis = IIS · RIS |
| Filter | **10 nF** to GND (C10–C40) | ADC anti-alias / noise stub |
| Target | Vis ≤ ~3.0 V at **~60 A** measurable | 60/52100 · 2700 ≈ **3.1 V** |
| **AmpsPerVolt TODO** | `≈ kILIS / RIS ≈ 19.3 A/V` | Firmware: calibrate on bench; document final in board overlay |

Soft EN from `OUT_PWM1..4`. Optional DIR on `OUT_IO1..4` not wired in rev a.

## ADIO (ADIO1–8)

| Ref | PN | Package | Why |
|-----|-----|---|-----|
| U11–U18 | **Infineon BTS7004-1EPP** | PG-TSDSO-14-22 | PROFET™ +2 12 V, **4.4 mΩ**, IL(NOM) **15 A** @ 85 °C — headroom above Razor **8 A continuous / ~10 A trip**. Single-channel maps 1:1 to eight ADIO stubs. |

Schematic still uses a simplified 5-pin stub symbol (EN/IS/VBAT/GND/OUT). PCB footprint is full TSDSO-14-22:

| Stub | Chip pin |
|---|---|
| EN | IN (2); DEN (3) tied to EN on PCB stub |
| IS | IS (4) |
| VBAT | VS thermal pad (15) |
| GND | GND (1) |
| OUT | OUT (8–10, 12–14) |

### ADIO current sense

| Param | Value | Notes |
|---|---|---|
| kILIS (typ) | **≈ 20000** | at IL(NOM) |
| RIS | **4.7 kΩ** (R101–R108) | Vis = (IL / kILIS) · RIS |
| Filter | **10 nF** (C101–C108) | |
| At 10 A | Vis ≈ 2.35 V | ADC-safe on 3.3 V Hellen analogs |
| **AmpsPerVolt TODO** | `≈ kILIS / RIS ≈ 4.26 A/V` | Calibrate per channel |

### Soft pull-ups

| Ref | Value | Net |
|-----|---|-----|
| R201–R208 | **4.7 kΩ** to **SENSOR_5V** | Series toward ADIOn node; **enable with FET/GPIO** already labeled (`OUT_IO9..13`, `IO1..3` per PINMAP). Rev a wires R to ADIO node + SENSOR_5V; discrete N-FET high-side enable still TODO if hard disconnect required. |

Voltage sense dividers to `IN_TPS` / `IN_PPS` / … are labeled on the ADIO sheet (V-sense stubs); ratio TBD with SENSOR_5V domain.

## Power entry

| Ref | PN / value | Role |
|-----|---|---|
| J2 | **M6 bolt-through bobbin** | VBAT+ (M6+), **north** power-field edge. Footprint `pdmrazora:M6_BoltThrough_Bobbin`: plated **6.5 mm** hole, **16 mm** Cu pad, 8× 0.8 mm stitch vias. Hardware: copper bobbin + M6×8 button-head, **4 N·m**, 25 mm² / 4 AWG (Link Razor). |
| J3 | **M6 bolt-through bobbin** | GND (M6−), **south** power-field edge. Same footprint as J2, placed independently (74.5 mm N–S span on the **109×98** nest, both on the x=80 centerline). The unused `M6_BoltThrough_Bobbin_x2` 25 mm pair is not on the PCB. |
| F1 | **150 A Mega / fusible-link TBD** | Input fuse placeholder |
| — | Ideal-diode / P-FET note | Reverse-polarity strategy (not a placed controller yet) |
| D1 | **SMBJ33CA** (24–40 V automotive TVS class) | VBAT ↔ GND |
| C1 | **100 µF 50 V** stub | Bulk |
| C2 | **100 nF** | HF bypass |
| R1 / R2 | **100 kΩ / 10 kΩ** | IGN_SW → **IN_VIGN** ≈ **11:1** (V = Vin · 10/110) for Hellen `H144_IN_VBATT` path |

**SENSOR_GND** (SuperSeal pins 6 & 12): keep as AGND island — **do not** bond to chassis or power-GND star.

## Firmware TODOs

1. Set `AmpsPerVolt` HP ≈ 19.3 and ADIO ≈ 4.26, then two-point calibrate.
2. Confirm IN_AUX3/AUX4 orientation on mega-mcu144 **0.7**.
3. `protected_gpio` bank: HP1–4 + ADIO1–4 first.
4. VBATT scaler: match R1/R2 11:1 in board config.

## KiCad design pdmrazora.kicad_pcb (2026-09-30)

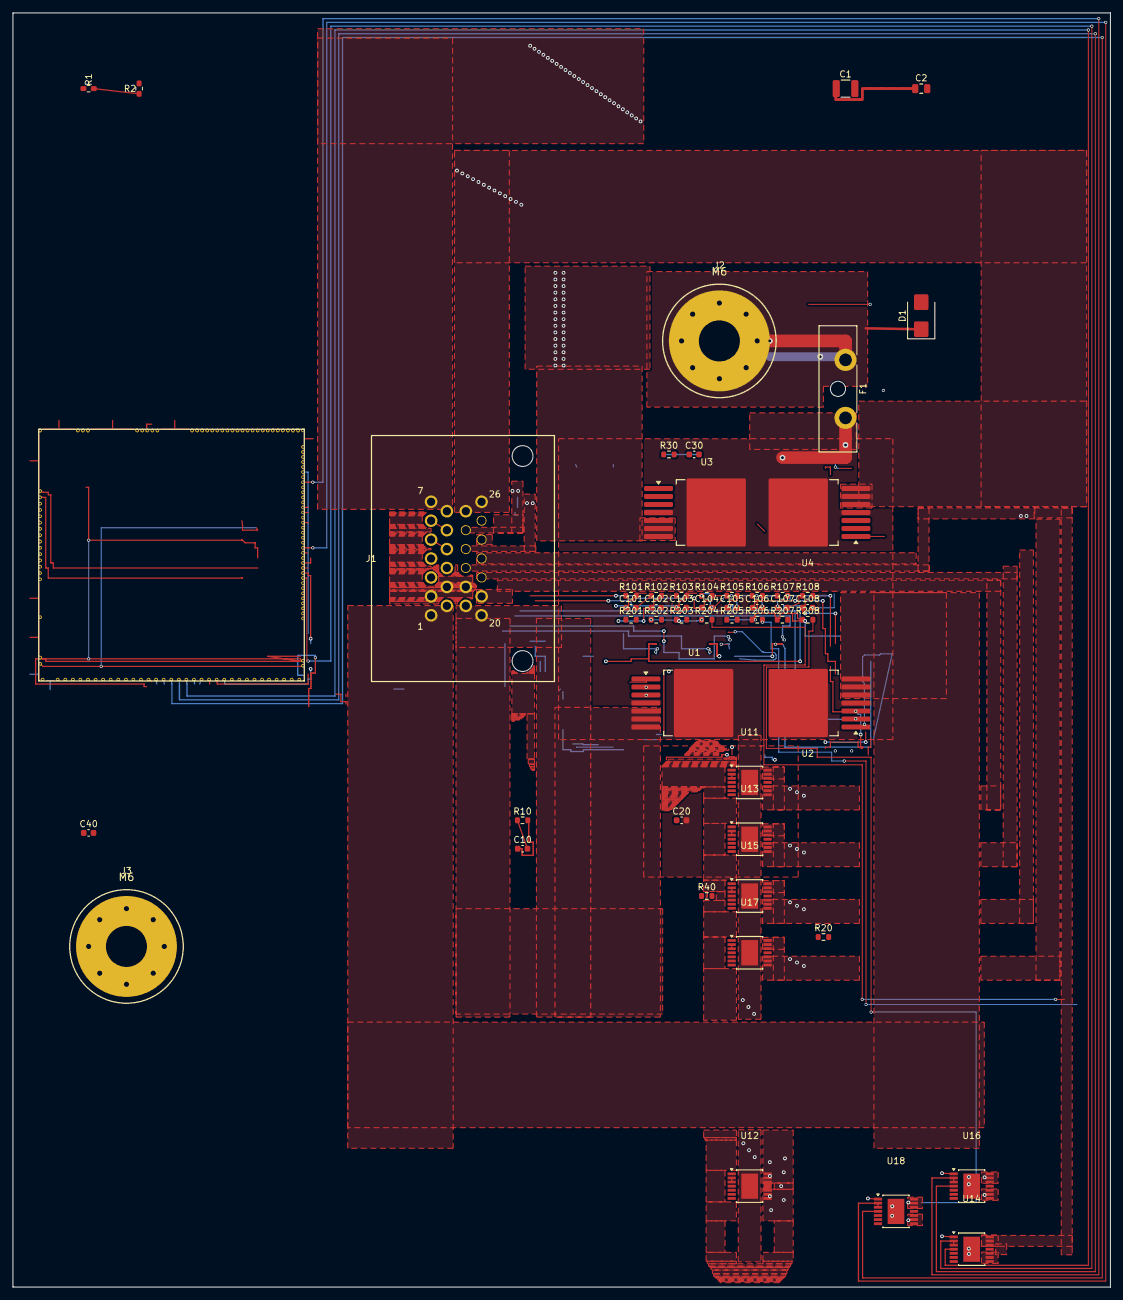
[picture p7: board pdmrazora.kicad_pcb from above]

Board: 2 copper layers, 174.0 x 202.0 mm, 54 parts (0 on the bottom side), 44 nets.

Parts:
C1: 100u_50V; C_1210_3225Metric
C2: 100n; C_0805_2012Metric
C10, C20, C30, C40, C101, C102, C103, C104, C105, C106, C107, C108: 10n; C_0603_1608Metric
D1: SMBJ33CA; D_SMB
F1: 150A_MEGA_TBD; Fuseholder_Blade_ATO_Littelfuse_Pudenz_2_Pin
J1: 6473418-1; TE_6473418-1_SuperSeal26_Vertical
J2: M6_VBAT; M6_BoltThrough_Bobbin
J3: M6_GND; M6_BoltThrough_Bobbin
M1000: Module:mega-mcu144/0.7; mega-mcu144
R1: 100k; R_0603_1608Metric
R2: 10k; R_0603_1608Metric
R10, R20, R30, R40: 2k7; R_0603_1608Metric
R101, R102, R103, R104, R105, R106, R107, R108, R201, R202, R203, R204, R205, R206, R207, R208: 4k7; R_0603_1608Metric
U1, U2, U3, U4: BTS50010-1TAD; TO-263-7_TabPin4
U11, U12, U13, U14, U15, U16, U17, U18: BTS7004-1EPP; Infineon_PG-TSDSO-14-22

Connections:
ADIO1: J1.21, R201.2, U11.8, U11.9, U11.10, U11.12, U11.13, U11.14
ADIO2: J1.2, J1.9, J1.15, R202.2, U12.8, U12.9, U12.10, U12.12, U12.13, U12.14
ADIO3: J1.22, R203.2, U13.8, U13.9, U13.10, U13.12, U13.13, U13.14
ADIO4: J1.16, R204.2, U14.8, U14.9, U14.10, U14.12, U14.13, U14.14
ADIO5: J1.23, R205.2, U15.8, U15.9, U15.10, U15.12, U15.13, U15.14
ADIO6: J1.17, R206.2, U16.8, U16.9, U16.10, U16.12, U16.13, U16.14
ADIO7: J1.24, R207.2, U17.8, U17.9, U17.10, U17.12, U17.13, U17.14
ADIO8: J1.18, R208.2, U18.8, U18.9, U18.10, U18.12, U18.13, U18.14
CANH: J1.3, M1000.W12
CANL: J1.10, M1000.W13
GND: C1.2, C2.2, C10.2, C20.2, C30.2, C40.2, C101.2, C102.2, C103.2, C104.2, C105.2, C106.2, C107.2, C108.2, D1.2, J3.1, M1000.G, R2.2, R10.1, R20.1, R30.1, R40.1, R101.1, R102.1, R103.1, R104.1, R105.1, R106.1, R107.1, R108.1, U1.1, U2.1, U3.1, U4.1, U11.1, U12.1, U13.1, U14.1, U15.1, U16.1, U17.1, U18.1
IGN_SW: J1.4, R1.1
IN_AUX1: C10.1, M1000.S13, R10.2, U1.3
IN_AUX2: C20.1, M1000.S12, R20.2, U2.3
IN_AUX3: C30.1, M1000.S11, R30.2, U3.3
IN_AUX4: C40.1, M1000.S10, R40.2, U4.3
IN_MAP1: C101.1, M1000.S21, R101.2, U11.4
IN_MAP2: C102.1, M1000.S20, R102.2, U12.4
IN_MAP3: C103.1, M1000.S19, R103.2, U13.4
IN_O2S: C104.1, M1000.S16, R104.2, U14.4
IN_O2S2: C105.1, M1000.S15, R105.2, U15.4
IN_RES1: C106.1, M1000.S17, R106.2, U16.4
IN_RES2: C107.1, M1000.S14, R107.2, U17.4
IN_RES3: C108.1, M1000.S18, R108.2, U18.4
IN_VIGN: M1000.N26, R1.2, R2.1
OUT_IO5: M1000.E7, U15.2, U15.3
OUT_IO6: M1000.E9, U16.2, U16.3
OUT_IO7: M1000.E23, U17.2, U17.3
OUT_IO8: M1000.E22, U18.2, U18.3
OUT_PWM1: M1000.E27, U1.2
OUT_PWM2: M1000.E17, U2.2
OUT_PWM3: M1000.E16, U3.2
OUT_PWM4: M1000.E15, U4.2
OUT_PWM5: M1000.E14, U11.2, U11.3
OUT_PWM6: M1000.E26, U12.2, U12.3
OUT_PWM7: M1000.E25, U13.2, U13.3
OUT_PWM8: M1000.E28, U14.2, U14.3
PWR_OUT1: J1.14, J1.20, U1.5, U1.6, U1.7
PWR_OUT2: J1.1, J1.8, U2.5, U2.6, U2.7
PWR_OUT3: J1.7, J1.13, U3.5, U3.6, U3.7
PWR_OUT4: J1.19, J1.26, U4.5, U4.6, U4.7
SENSOR_5V: J1.5, J1.11, M1000.E38, M1000.N30, M1000.W2, R201.1, R202.1, R203.1, R204.1, R205.1, R206.1, R207.1, R208.1
SENSOR_GND: J1.6, J1.12, M1000.E39, M1000.W1
VBAT: C1.1, C2.1, D1.1, F1.1, F1.2, J2.1, M1000.N27, U1.4, U2.4, U3.4, U4.4, U11.15, U12.15, U13.15, U14.15, U15.15, U16.15, U17.15, U18.15

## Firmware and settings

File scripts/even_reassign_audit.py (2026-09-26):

#!/usr/bin/env python3
"""Upper bound on a SuperSeal pin reassignment for ADIO4 / ADIO6 / ADIO8.

Read-only. Does not move footprints, pour copper, bridge F1, pour
SENSOR_GND, export gerbers, or replay cut_crossings_sexp.py.

Every SuperSeal pin that is not already a preserved high-current net is
treated as the candidate net at once (pads are not obstacles). That is
the widest corridor pin reassignment can open. Preserved copper stays
an obstacle: PWR_OUT1–4, ADIO1/2/3/5/7, VBAT at priority >= 2, and VBAT
that reaches the fuse band. Priority-1 GND pours are not obstacles.
Signal tracks and GND tracks are ignored, because a new pour may push
them aside. Pads are not ignored.

Series neck is the minimum F+B of one continuous path. F and B add on
the same XY. A result under 3.47 mm is a hold: this file does not
derate the 8 A line and does not assume 2 oz.
"""
from __future__ import annotations

import heapq
import math
from pathlib import Path

import numpy as np
import pcbnew
from PIL import Image, ImageDraw
from scipy import ndimage

PCB = Path(__file__).resolve().parents[1] / "pdmrazora.kicad_pcb"
CLR = 0.20
NEED = 3.47
STEP = 0.30
X0, Y0, X1, Y1 = 8.0, 28.0, 140.0, 162.0
# Pins whose nets must stay. Everything else on J1 may be reassigned.
LOCKED = {
    "1", "2", "7", "8", "9", "13", "14", "15", "19", "20", "21", "22", "23", "24", "26",
}
PRESERVE = {
    "PWR_OUT1", "PWR_OUT2", "PWR_OUT3", "PWR_OUT4",
    "ADIO1", "ADIO2", "ADIO3", "ADIO5", "ADIO7", "VBAT",
}

board = pcbnew.LoadBoard(str(PCB))
F_Cu = pcbnew.F_Cu
B_Cu = pcbnew.B_Cu
W = int(round((X1 - X0) / STEP)) + 1
H = int(round((Y1 - Y0) / STEP)) + 1


def mm(v):
    return pcbnew.ToMM(v)


def xy_to_px(x, y):
    return int(round((x - X0) / STEP)), int(round((y - Y0) / STEP))


def px_to_xy(c, r):
    return X0 + c * STEP, Y0 + r * STEP


def collect():
    pads, zones, tracks = [], [], []
    for fp in board.GetFootprints():
        ref = fp.GetReference()
        for pad in fp.Pads():
            if not (pad.IsOnLayer(F_Cu) or pad.IsOnLayer(B_Cu)):
                continue
            pos = pad.GetPosition()
            attr = pad.GetAttribute()
            pads.append(
                {
                    "ref": ref,
                    "num": pad.GetNumber(),
                    "x": mm(pos.x),
                    "y": mm(pos.y),
                    "w": mm(pad.GetSize().x),
                    "h": mm(pad.GetSize().y),
                    "net": pad.GetNetname(),
                    "pth": attr == pcbnew.PAD_ATTRIB_PTH,
                    "npth": attr == pcbnew.PAD_ATTRIB_NPTH,
                    "f": pad.IsOnLayer(F_Cu) or attr in (pcbnew.PAD_ATTRIB_PTH, pcbnew.PAD_ATTRIB_NPTH),
                    "b": pad.IsOnLayer(B_Cu) or attr in (pcbnew.PAD_ATTRIB_PTH, pcbnew.PAD_ATTRIB_NPTH),
                    "circle": pad.GetShape() == pcbnew.PAD_SHAPE_CIRCLE
                    or attr in (pcbnew.PAD_ATTRIB_PTH, pcbnew.PAD_ATTRIB_NPTH),
                    "bb": (
                        mm(pad.GetBoundingBox().GetLeft()),
                        mm(pad.GetBoundingBox().GetTop()),
                        mm(pad.GetBoundingBox().GetRight()),
                        mm(pad.GetBoundingBox().GetBottom()),
                    ),
                }
            )
    for i in range(board.GetAreaCount()):
        z = board.GetArea(i)
        layers = []
        try:
            for L in z.GetLayerSet().Seq():
                if L == F_Cu:
                    layers.append("F")
                elif L == B_Cu:
                    layers.append("B")
        except Exception:
            if z.GetLayer() == F_Cu:
                layers.append("F")
            elif z.GetLayer() == B_Cu:
                layers.append("B")
        pts = []
        ol = z.Outline()
        if ol.OutlineCount() > 0:
            ch = ol.Outline(0)
            for k in range(ch.PointCount()):
                p = ch.CPoint(k)
                pts.append((mm(p.x), mm(p.y)))
        zones.append(
            {
                "name": z.GetZoneName() if hasattr(z, "GetZoneName") else "",
                "net": z.GetNetname(),
                "pri": z.GetAssignedPriority(),
                "rule": z.GetIsRuleArea(),
                "layers": layers,
                "pts": pts,
            }
        )
    for t in board.GetTracks():
        net = t.GetNetname()
        if net == "GND" or net not in PRESERVE:
            # Signal and GND tracks may be pushed by a pour. Preserve-net
            # tracks stay. The candidate net's own tracks are not obstacles.
            continue
        if t.GetClass() == "PCB_VIA":
            tracks.append(
                {
                    "kind": "via",
                    "x": mm(t.GetPosition().x),
                    "y": mm(t.GetPosition().y),
                    "w": mm(t.GetWidth()),
                    "net": net,
                    "layers": ("F", "B"),
                }
            )
        else:
            lay = "F" if t.GetLayer() == F_Cu else "B" if t.GetLayer() == B_Cu else None
            if not lay:
                continue
            tracks.append(
                {
                    "kind": "seg",
                    "x0": mm(t.GetStart().x),
                    "y0": mm(t.GetStart().y),
                    "x1": mm(t.GetEnd().x),
                    "y1": mm(t.GetEnd().y),
                    "w": mm(t.GetWidth()),
                    "net": net,
                    "layers": (lay,),
                }
            )
    return pads, zones, tracks


def hard_zone(z):
    if z["rule"]:
        return True
    if z["net"] in PRESERVE and z["net"] != "VBAT":
        return True
    if z["net"] == "VBAT":
        if z["pri"] >= 2:
            return True
        ys = [p[1] for p in z["pts"]] or [0]
        return min(ys) < 26
    return False


def draw_disc(draw, x, y, r):
    if r <= 0:
        return
    c, rr = xy_to_px(x, y)
    rad = r / STEP
    draw.ellipse((c - rad, rr - rad, c + rad, rr + rad), fill=1)


def draw_seg(draw, x0, y0, x1, y1, width):
    r = max(width / 2 / STEP, 0.5)
    c0, r0 = xy_to_px(x0, y0)
    c1, r1 = xy_to_px(x1, y1)
    draw.line((c0, r0, c1, r1), fill=1, width=int(math.ceil(r * 2)))
    draw.ellipse((c0 - r, r0 - r, c0 + r, r0 + r), fill=1)
    draw.ellipse((c1 - r, r1 - r, c1 + r, r1 + r), fill=1)
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

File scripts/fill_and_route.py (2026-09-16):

#!/usr/bin/env python3
"""Fill pours + selective copper for pdmrazora. Avoid dense meshes / shared B.Cu lanes."""
from __future__ import annotations

import re
import sys
from collections import defaultdict
from pathlib import Path

import pcbnew
from pcbnew import (
    VECTOR2I, FromMM, ToMM, PCB_TRACK, PCB_VIA, ZONE, F_Cu, B_Cu, ZONE_FILLER,
)

ROOT = Path(__file__).resolve().parents[1]
PCB_PATH = ROOT / "pdmrazora.kicad_pcb"
STATUS = ROOT / "scripts" / "copper_status.txt"


def mm(x, y=None):
    if y is None:
        return FromMM(x)
    return VECTOR2I(FromMM(x), FromMM(y))


def ensure_net(board, name):
    ni = board.FindNet(name)
    if ni is not None and ni.GetNetCode() > 0:
        return ni
    ni = pcbnew.NETINFO_ITEM(board, name)
    board.Add(ni)
    return ni


def pad_xy(pad):
    p = pad.GetPosition()
    return ToMM(p.x), ToMM(p.y)


def clear_tracks(board):
    tracks = list(board.GetTracks())
    for t in tracks:
        board.Remove(t)


def set_rect_corners(z, x1, y1, x2, y2):
    assert z.GetNumCorners() == 4
    z.SetCornerPosition(0, mm(x1, y1))
    z.SetCornerPosition(1, mm(x2, y1))
    z.SetCornerPosition(2, mm(x2, y2))
    z.SetCornerPosition(3, mm(x1, y2))


def add_rect_zone(board, netname, layer, x1, y1, x2, y2, clearance=0.25, min_thickness=0.3):
    z = ZONE(board)
    z.SetNet(ensure_net(board, netname))
    z.SetLayer(layer)
    z.SetIsRuleArea(False)
    z.SetLocalClearance(FromMM(clearance))
    z.SetMinThickness(FromMM(min_thickness))
    z.SetPadConnection(pcbnew.ZONE_CONNECTION_FULL)
    for x, y in [(x1, y1), (x2, y1), (x2, y2), (x1, y2)]:
        z.AppendCorner(mm(x, y), -1)
    board.Add(z)
    return z


def add_track(board, x1, y1, x2, y2, width_mm, netname, layer=F_Cu):
    if abs(x1 - x2) < 1e-4 and abs(y1 - y2) < 1e-4:
        return None
    tr = PCB_TRACK(board)
    tr.SetStart(mm(x1, y1))
    tr.SetEnd(mm(x2, y2))
    tr.SetWidth(FromMM(width_mm))
    tr.SetLayer(layer)
    tr.SetNet(ensure_net(board, netname))
    board.Add(tr)
    return tr


def add_via(board, x, y, netname, drill=0.3, size=0.6):
    v = PCB_VIA(board)
    v.SetPosition(mm(x, y))
    v.SetDrill(FromMM(drill))
    try:
        v.SetFrontWidth(FromMM(size))
    except Exception:
        try:
            v.SetWidth(F_Cu, FromMM(size))
        except Exception:
            pass
    v.SetNet(ensure_net(board, netname))
    board.Add(v)
    return v


def fp_map(board):
    return {fp.GetReference(): fp for fp in board.GetFootprints()}


def get_pad(fps, ref, num):
    for pad in fps[ref].Pads():
        if pad.GetNumber() == str(num):
            return pad
    raise KeyError(f"{ref}.{num}")


def downgrade_to_k8(path: Path):
    text = path.read_text()
    text = re.sub(r"\(version \d+\)", "(version 20240108)", text, count=1)
    text = re.sub(r'\(generator_version "[^"]+"\)', '(generator_version "8.0")', text, count=1)
    text = re.sub(r"\n\t\(embedded_fonts (yes|no)\)", "", text)
    k8_layers = """(layers
		(0 "F.Cu" signal)
		(31 "B.Cu" signal)
		(33 "F.Adhes" user "F.Adhesive")
		(32 "B.Adhes" user "B.Adhesive")
		(35 "F.Paste" user)
		(34 "B.Paste" user)
		(37 "F.SilkS" user "F.Silkscreen")
		(36 "B.SilkS" user "B.Silkscreen")
		(39 "F.Mask" user)
		(38 "B.Mask" user)
		(40 "Dwgs.User" user "User.Drawings")
		(41 "Cmts.User" user "User.Comments")
		(42 "Eco1.User" user "User.Eco1")
		(43 "Eco2.User" user "User.Eco2")
		(44 "Edge.Cuts" user)
		(45 "Margin" user)
		(47 "F.CrtYd" user "F.Courtyard")
		(46 "B.CrtYd" user "B.Courtyard")
		(49 "F.Fab" user)
		(48 "B.Fab" user)
		(50 "User.1" user)
		(51 "User.2" user)
		(52 "User.3" user)
		(53 "User.4" user)
	)"""
    text = re.sub(r"\(layers\n.*?\n\t\)", k8_layers, text, count=1, flags=re.S)
    path.write_text(text)
    assert "20240108" in path.read_text()[:250]
    assert 'generator_version "8.0"' in path.read_text()[:250]


def rebuild_zones(board):
    assert board.GetAreaCount() >= 16
    set_rect_corners(board.GetArea(1), 85, 55, 140, 100)  # VBAT HP
    set_rect_corners(board.GetArea(2), 1, 1, 149, 129)     # GND B
    set_rect_corners(board.GetArea(3), 1, 85, 70, 118)     # GND F entry
    set_rect_corners(board.GetArea(4), 86.5, 58.5, 92.5, 63.5)
    set_rect_corners(board.GetArea(5), 109.5, 58.5, 115.5, 63.5)
    set_rect_corners(board.GetArea(6), 86.5, 80.5, 92.5, 85.5)
    set_rect_corners(board.GetArea(7), 109.5, 80.5, 115.5, 85.5)
    for i, box in enumerate([
        (71.5, 13.5, 74.5, 19.0), (89.5, 13.5, 92.5, 19.0),
        (107.5, 13.5, 110.5, 19.0), (125.5, 13.5, 128.5, 19.0),
        (71.5, 39.5, 74.5, 45.0), (89.5, 39.5, 92.5, 45.0),
        (107.5, 39.5, 110.5, 45.0), (125.5, 39.5, 128.5, 45.0),
    ]):
        set_rect_corners(board.GetArea(8 + i), *box)
    # Extra VBAT
    add_rect_zone(board, "VBAT", F_Cu, 10, 88, 70, 118, 0.3, 0.4)
    add_rect_zone(board, "VBAT", F_Cu, 55, 115, 100, 128, 0.3, 0.4)
    add_rect_zone(board, "VBAT", F_Cu, 55, 7, 140, 12, 0.25, 0.3)
    add_rect_zone(board, "VBAT", F_Cu, 55, 33, 140, 37, 0.25, 0.3)
    add_rect_zone(board, "GND", F_Cu, 85, 55, 140, 100, 0.25, 0.3)
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

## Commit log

2026-09-15 Add Hellen-One Razor PDM frame matching Link SuperSeal pinout
    Populate hellen-example skeleton (workflows, submodules, revision.txt),
    authoritative CONNECTOR/PINMAP/spec docs, and pdmrazora KiCad frame with
    exact Razor 26-pin nets, M6 power stubs, and HP/ADIO TODO placeholders.
    MCU target: mega-mcu144 >= 0.7. Not HELLCORE.
    [pdmrazora.kicad_pcb, pdmrazora.kicad_sch]
2026-09-15 Place mega-mcu144 0.7 and stub HP PROFET x4 / ADIO x8 stages
    Put the 0.7 module on the 160x120 mm frame (M1000, 0°), wire PINMAP edge labels to Razor SuperSeal nets, and replace schematic TODOs with HP/ADIO hierarchical sheets (PN TBD).
    [ADIO.kicad_sch, HP.kicad_sch, MM144.kicad_sch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]
2026-09-15 Clear fab blockers 1–4: SuperSeal 9-6437287-8, PROFET PNs, power entry, PCB place
    - Replace Conn_02x13 pin-header with TE/AMP SuperSeal 1.0 26-way
    (9-6437287-8, keying 1) via pdmrazora.pretty footprint (6473423-1 pattern)
    - HP: keep BTS50010-1TAD; add RIS 2k7 + 10n; fix IN/IS wiring
    - ADIO: BTS7004-1EPP; RIS 4k7 + soft PU 4k7 to SENSOR_5V; fix EN/IS wiring
    - Power entry: fuse/TVS/bulk stubs + IGN_SW 100k/10k (~11:1) → IN_VIGN
    - PCB: place SuperSeal, HP×4, ADIO×8 with nets; outline 180×140; thermal zones
    - Document PNs, kILIS, AmpsPerVolt TODOs in HARDWARE_BOM.md / BOARD.md
    Do not touch HELLCORE.
    [ADIO.kicad_sch, HP.kicad_sch, pdmrazora.kicad_pcb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]
2026-09-15 Downgrade KiCad project from 9 to 8 format
    Rewrite PCB/schematics to KiCad 8 anchors (pcb 20240108, sch 20231120,
    generator_version 8.0) so KiCad 8 can open without the "needs 9.0+" error.
    Matches mega-mcu144 0.7. Docs: open with KiCad 8.x (9 OK; 6/7 will not).
    [ADIO.kicad_sch, HP.kicad_sch, MM144.kicad_sch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]
2026-09-15 Nest PDM floorplan and add power/ADIO pour scaffolding
    Rearrange all 53 footprints onto a 150×130 mm Edge.Cuts board (aux
    origin bottom-left), with M1000 clear for Hellen merge, J1 on the
    bottom edge, HP/ADIO clustered with local sense passives, and pour
    outlines for VBAT/GND/PWR_OUT/ADIO. Length routing of control/sense
    remains ratsnest after fill — aggressive autoroute introduced shorts.
    [pdmrazora.kicad_pcb]
2026-09-16 Fill pours and selectively route copper on pdmrazora
    Complete zone fills for VBAT/GND/PWR_OUT/ADIO (M1000 keepout
    respected) and add selective Manhattan tracks + vias for power
    entry, HP/ADIO outs, local sense, IGN/CAN/SENSOR spines, and
    EN/IS stubs to M1000. Tracks 0→328, DRC unconnected 254→97.
    KiCad 8 headers preserved after pcbnew 9 save. Interactive DRC
    cleanup of remaining shorts/crossings still needed.
    [pdmrazora.kicad_pcb]
2026-09-16 Clear DRC shorts/crossings; SENSOR_5V PU taps and GND stitches
    Surgical UUID-based conflict deletes plus gated PWR/ADIO/CAN restore
    bring shorts 94→1 (J2 header only) and crossings 110→33. SENSOR_5V
    taps to R201–R208 and GND stitch vias added. KiCad 8 format kept;
    HELLCORE untouched. Unconnected rises (conflict copper removed).
    [pdmrazora.kicad_pcb]
2026-09-16 Route EN exclusive B lanes; IS local + gated long-haul
    After DRC cleanup 5f0f389: reconnect all 12 EN nets on exclusive B.Cu
    corridors (HP south-ring, ADIO top/bot cols) and rebuild IS U–R–C local
    sense without new shorts. Keep three IS long-haul nets (AUX1/AUX4/MAP1)
    via per-net DRC gate; nine IS ratsnest remain. Unconnected 145→122;
    shorts stay at J2-only; K8 headers preserved; HELLCORE untouched.
    [pdmrazora.kicad_pcb]
2026-09-16 Fix BOARD.md DRC crossing count for EN/IS commit
2026-09-21 Route remaining 9 IS long-haul nets and thin EN B lanes
    Gated B.Cu south-ring closes AUX2/3, MAP2/3, O2S/O2S2, and RES1–3
    without new shorts (J2 VBAT↔GND remains the only short). EN B
    re-geometry stays north of PWR / south of SENSOR and keeps EN/IS
    closed. Crossings rise 87→119 from IS highways vs ADIO/PWR; F
    westbound + west-corridor cut is staged next. KiCad stem stays
    pdmrazora; HELLCORE untouched; no PowerCore branding rename.
    [pdmrazora.kicad_pcb]
2026-09-21 Trim ADIO J1 U-turns and drop orphan PWR south stubs
    After the 9 IS long-haul fill (crossings 119), shift ADIO1–8 B.Cu U-turns
    from y=114–118 to 105.4–106.9 so they sit north of the IS south-ring and
    J1 mounting. Delete PWR_OUT B copper with y>110 that never reached the
    J1 vias. Shorts stay J2-only; EN/IS stay closed. Crossings 87→106.
    F westbound / via-hop / nested re-pair still short through F1/J1.
    KiCad stem stays pdmrazora; no PowerCore branding; HELLCORE untouched.
    [pdmrazora.kicad_pcb]
2026-09-21 Cut DRC crossings 106→89 with gated EN/ADIO F-hops
    Move AUX1 off J1 pins, F-hop EN over SENSOR x=52 and ADIO U-turns
    across IS feeders. Shorts stay J2-only; EN/IS unconnected stay 0.
    [pdmrazora.kicad_pcb]
2026-09-21 Rename user-facing branding to PowerCore
    Keep KiCad stem pdmrazora and Link Razor loom/connector compatibility.
    No copper or routing changes; PCB title-block comment only.
    [MM144.kicad_sch, pdmrazora.kicad_pcb, pdmrazora.kicad_sch]
2026-09-21 Redesign PowerCore floorplan: M6 bobbins, 104x93, vertical SuperSeal EMI split
    Replace the J2 2.54 mm pin-header with M6 bolt-through bobbins, shrink
    Edge.Cuts to Link Razor-class 104x93 mm (aux origin at bottom-left), place
    a vertical SuperSeal as an EMI wall between mega-mcu144 and the PROFET
    power half, and align the M1000 keepout/value with hellen-one 0.7.
    Old Manhattan copper is dropped with the move; coarse VBAT/GND pours remain
    for the new outline. EN/IS/ADIO routing is left as human copper polish.
    [pdmrazora.kicad_pcb, pdmrazora.kicad_sch]
2026-09-21 Route critical nets on 104×93 PowerCore EMI-split floorplan
    Add sexp routing for VBAT/GND, EN/IS (HP1–4 + ADIO1–8), PWR_OUT,
    ADIO, CAN, and SENSOR on the new mechanical nest without moving
    footprints or touching HELLCORE. EN uses exclusive B.Cu highways;
    IS is local F plus B long-haul; power stays east of the SuperSeal
    except the N27 north corridor. kicad-cli DRC was unavailable;
    GND pad islands complete on zone fill.
    [pdmrazora.kicad_pcb]
2026-09-21 Respect Jeoff caveats: spread east vias, verify SuperSeal keepout
    Widen TE 6473418-1 courtyard to 39×29 mm (catalog vertical D) so it
    fits the M1000–HP gap; draw the product-page 39×36.5 mm shroud on
    Cmts.User (it overlaps U1 and was not forced into F.CrtYd). Spread
    ADIO/EN/PWR vias off the 0.32 mm packs, skip extra GND stitches that
    would short, leave the ATO fuse and the 150×130 scripts untouched.
    Via-pack scan is now 0; EN/IS still connected; kicad-cli DRC still
    unavailable.
    [pdmrazora.kicad_pcb]
2026-09-21 Fill VBAT/GND pours and stitch M6/HP tabs on 104x93 PowerCore
    ZONE_FILLER in KiCad 8.0.9 on pdmrazora: solid VBAT/GND pad connect, HP F
    island expanded over TO-263 tabs, B.Cu VBAT under entry and U1/U2 tabs
    (stops north of EN). Extra stitch vias on M6 bobbins and HP tabs. No
    SENSOR pour (none existed; SENSOR_GND stays off chassis). F1 ATO left.
    kicad-cli DRC: shorts 199 (unchanged vs unfilled copper), crossings 178,
    unconnected 131→100 (VBAT 9→2). 13 packed-east GND pads remain for human
    via placement. Do not replay 150x130 cut_crossings scripts.
    [pdmrazora.kicad_pcb]
2026-09-21 Split VBAT/GND M6 bobbins onto opposite power-field edges (#9)
    Replace the 25 mm dual-bobbin J2 with two independent single M6
    footprints so VBAT+ (north) and GND (south) are no longer paired on
    the east edge, and neither shares the mega-mcu144 west side. HP and
    ADIO sit between them. Razor-class 104x93 outline and vertical
    SuperSeal EMI wall are unchanged. Paired-spine copper is stripped;
    zone outlines await a follow-up fill.
    [pdmrazora.kicad_pcb, pdmrazora.kicad_sch]
2026-09-21 Route critical nets and fill VBAT/GND pours on split-bobbin PowerCore (#10)
    Rebuild copper on the PR #9 J2-north / J3-south 104×93 nest (placements
    unchanged, pdmrazora stem unchanged). EN/IS exclusive lanes, SuperSeal
    fanouts, M1000 keepout, no SENSOR_GND pour. Zones filled solid in pcbnew
    8.0.9. Packed-east shorts/crossings remain for human polish.
    [pdmrazora.kicad_pcb]
2026-09-22 Clear packed-east shorts without bridging the fuse. (#11)
    Rotate U3/U4 so their pins clear the tabs, nudge J1 and the sense parts off overlapping copper, and rebuild carrier tracks from KiCad pad coordinates. kicad-cli 8.0.9 shorts and crossings drop to 0; 75 unconnected items, courtyards, and the M1000 padstack remain.
    [pdmrazora.kicad_pcb]
2026-09-22 Close the carrier ratsnests that still clear 0.20 mm. (#12)
    Unconnected items go from 75 to 60 with shorts, crossings, and clearance still at 0. IN_RES3 and five GND stubs join. The SuperSeal pin field, the M1000 north wall, and the post-fuse VBAT islands stay open because a 0.20/0.20 track does not fit. F1 is not bridged and the R1 courtyard nudge was reverted after it shorted IN_VIGN.
    [pdmrazora.kicad_pcb]
2026-09-22 Spread the ADIO columns 0.35 mm so a via fits between packages. (#13)
    Column 0 stays. Columns 1–3 move east 0.35 / 0.70 / 1.05 mm with their local copper. The IN_AUX spines shift just enough that the new pads do not land on them. Shorts, crossings, and clearance stay 0. Unconnected stays 60: the 0.80 mm bus pitch still blocks the IS layer change, and the 0.40 mm SuperSeal-to-M1000 gap does not open by moving J1 east or M1000 west.
    [pdmrazora.kicad_pcb]
2026-09-22 Grow PowerCore to 109x98 with symmetric drivers and exposed HP copper. (#14)
    Edge.Cuts is 109x98 mm. HP and ADIO drivers mirror about x=80 between the split M6 bobbins. M1000 keepout punches the pours, and PWR_OUT1-4 are carried on F.Cu with solder-mask openings.
    [pdmrazora.kicad_pcb]
2026-09-22 Close carrier ratsnests on the 109x98 PowerCore board. (#15)
    Unconnected items drop from 129 to 64. Shorts, crossings, clearance, and hole-to-hole stay at 0. Driver-side ADIO and the OUT/IN layer mismatches are tied. The J1 ADIO pins, IGN_SW, and the fuse gap stay open. PWR_OUT mask openings are unchanged and no footprints moved.
    [pdmrazora.kicad_pcb]
2026-09-22 Open SuperSeal exits and stitch carrier GND on the 109×98 board (#16)
    * Open SuperSeal exits and stitch carrier GND on the 109x98 board.
    Move the SENSOR_GND spine off x=38.40 onto a west bypass so ADIO2/4/6/8
    can leave J1, and tie the pour-reachable carrier pads. Unconnected 64 to 53.
    F1 stays open, the keepout stays empty, and the 358 HP mask openings are unchanged.
    * Stitch C2 and C108 onto the GND pour.
    Both ties land in the existing B.Cu pour. Unconnected 53 to 51, VBAT stays 10, and the fuse, keepout, and 358 mask openings are unchanged.
    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
    [pdmrazora.kicad_pcb]
2026-09-22 Land ADIO6 and stitch IN_RES2, R10, C105, C106 (#17)
    * Land ADIO6 through the GND pour neck.
    Jog OUT_IO7 off x=72.4, run ADIO6 onto the driver, and stitch the
    cut-off B.Cu GND island into the J3 pour so the hop does not add a ratsnest.
    * Land IN_RES2 and stitch R10, C105, and C106.
    Widen the B.Cu slot so IN_RES2, C105, and C106 can via onto copper
    already on those nets, and jog the R10 slot so that pad ties to the
    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
    [pdmrazora.kicad_pcb]
2026-09-22 Document ADIO-rest blockers after a serious keepout attempt. (#18)
    Replicate the ADIO6 pour-keepout pattern for the remaining ADIO nets.
    Every candidate that closed an ADIO ratsnest opened a GND island
    (ADIO5 also grew VBAT), so no copper was kept. Record mm blockers,
    DRC table, and neck crop; unconnected stays 46.
2026-09-23 GHA says update kicad6-libraries
2026-09-24 Widen the post-fuse VBAT feeder and record the 1 oz track-width audit. (#19)
    IPC-2221 external 1 oz at 20 °C needs 16.7 mm for 25 A and 3.5 mm for 8 A.
    HP and ADIO runs are already against clearance, so those tracks stay put.
    The F1.2 strap was 2.0 mm into a 53 mm pour; a 17.5 mm F.Cu zone replaces
    that neck without bridging the fuse. Netclasses now default to those widths.
    [pdmrazora.kicad_pcb]
2026-09-25 Grow board for HP 1 oz ampacity (#20)
    PWR_OUT1–4 now have continuous pour necks at the IPC-2221A 16.72 mm line. J1, J3, and F1 stay put; M1000 and the west drivers move only enough to open the corridors.
    [pdmrazora.kicad_pcb]
2026-09-25 Pour ADIO1/3/5/7 at 1 oz 8 A width (#21)
    ADIO1, ADIO3, ADIO5, and ADIO7 leave J1 on F+B, or on a 3.80 mm B.Cu leg, and the series neck meets 3.47 mm. The even SuperSeal pins stay open because the pin-field aperture is 0.60 mm. HP pours are 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
    [pdmrazora.kicad_pcb]
2026-09-25 Even ADIO fanout audit: 1 oz cage stays at 1.20 mm F+B (#22)
    The widest corridor out of ADIO2/4/6/8 is still the 0.60 mm SuperSeal door on each layer. Copper, drivers, and the Razor pin map stay as they were.
2026-09-26 Pour ADIO2 at 4.53 mm through SuperSeal NC pins 2 and 9 (#23)
    ADIO2 series neck 4.53 mm F+B via SuperSeal pins 2+9 same-net on PCB (loom table still N/C). Odd ADIO + HP intact. Hard DRC 0. ADIO4/6/8 not poured (~0.80 mm); copper under current constraints exhaus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
    [pdmrazora.kicad_pcb, pdmrazora.kicad_sch]
2026-09-26 Hold ADIO4/6/8 loom reassignment: 1 oz paths stay under 3.47 mm (#24)
    Upper-bound SuperSeal reassignment audit: ADIO4 ceiling 2.60 mm; ADIO6/8 no positive-width path to drivers while preserving ADIO2/odd/HP at 1 oz. Board and loom unchanged. No 2 oz or derate invented.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
2026-09-26 Board-wide 2 oz so ADIO4/6/8 clear 8 A at 1.74 mm (#25)
    Board-wide 2 oz (70 µm F/B). ADIO4/6/8 necks 1.76 mm (≥1.74 mm for 8 A). U14/U16/U18 moved SE; U12 stays; Razor loom unchanged. Pads 16/17/18/22–25 at 1.60 mm. Hard DRC 0; unconnected 174 (moved-driv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
    [pdmrazora.kicad_pcb]
2026-09-26 Reconnect moved drivers U14/U16/U18 and even sense taps
    VBAT, GND, EN, and IS land on the moved drivers, and R204/R206/R208 tap ADIO4/6/8. Unconnected goes from 174 to 158. Hard DRC stays 0. The 2 oz series necks are unchanged.
    [pdmrazora.kicad_pcb]
2026-09-30 Close leftover rats and restore ADIO5/ADIO8 2 oz necks (#27)
    Jeoff thin-review MERGE. Hard DRC 0; unconnected 158→141; ADIO5 1.83 mm / ADIO8 drop 1.77 mm. ADIO2/HP/Razor loom untouched. Create-board CI still fails pre-existing pdmrazor vs pdmrazora naming (same as #26+); not a board regression.
    [pdmrazora.kicad_pcb]
2026-10-21 Drop even ADIO channels to 4 HP + 4 low-current outputs. (#28)
    Remove ADIO2/4/6/8 drivers, sense parts, and pours, leave their SuperSeal pins no-connect, and keep the odd 8 A necks and the HP pours. Rewire J1 so schematic pin numbers match the loom, and stop the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
